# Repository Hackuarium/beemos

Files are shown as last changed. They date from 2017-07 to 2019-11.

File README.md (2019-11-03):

<p align="center">
  
</p>

# BeeMoS - honey Bee Monitoring System<br/> (under development)

_[Lire en français](README.fr.md)_

The BeeMoS project is an open source bee hive monitoring system developed at the open science lab [Hackuarium](http://www.hackuarium.ch), Route de Crochy 20, Ecublens, Switzerland.

Please fee free to [contact us](https://form.jotformeu.com/71600609780354) if you would like more information.

# Objectives

Build and program an open source bee monitoring system capable of the following objectives:

- [x] Track the activity of the hives to study the behaviour of bees and monitor their health.
- [x] Track changes in the hive's weight over time to detect sudden and gradual changes (swarming, honey production ...).
- [x] Measures environmental variables including temperature, humidity, light and atmospheric pressure and study their effect on the bees.
- [ ] Send the data to a remote server for analysis, visualization or to notify the user if something unusual happens.

# Cloning the project

This project uses SUBMODULES

In order to clone use:

`git clone --recurse-submodules https://github.com/hackuarium/beemos`

To update the submodules, enter the folder you created ("beemos") and use:

`git submodule update --recursive --remote`

# Modules

To achieve the above objectives, the project follows a modular design with different hardware components. We use the I2C protocol to make modulles (i.e the boards) communicate to each other while using RJ-12 connectors in order to allow easy plugging/deplugging of different modules.

[**Counter**](counter-i2c/README.md): Counts bees entering and exiting the hive over time using infrared (IR) sensors. Each sensor consists in an IR emitter-receiver, the passage of a bee under the sensor modifies the reflected IR signal. A pair of IR sensors is used for each tunnel so that the direction of bees (i.e. entering or exiting the hive) can be determined.

<p align="center">
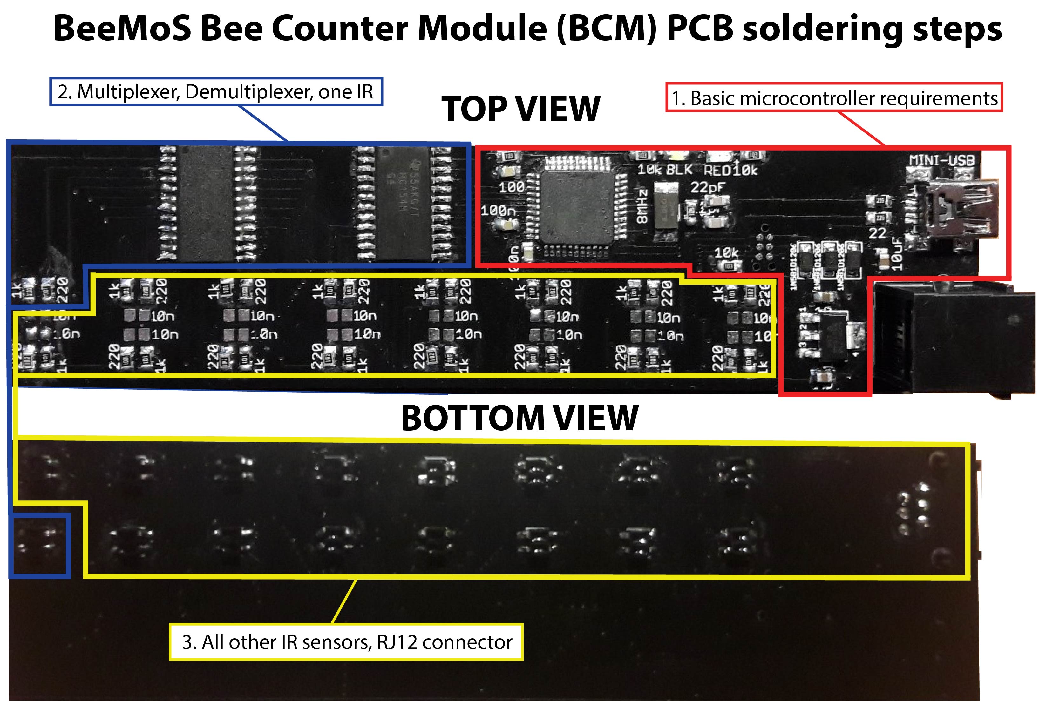
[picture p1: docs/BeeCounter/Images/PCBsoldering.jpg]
  
</p>

Here is the orientation of the IR sensors at the back of the PCB. Be careful, the orientation of the Eagle file is seen from the top of the PCB.
<p align="center">
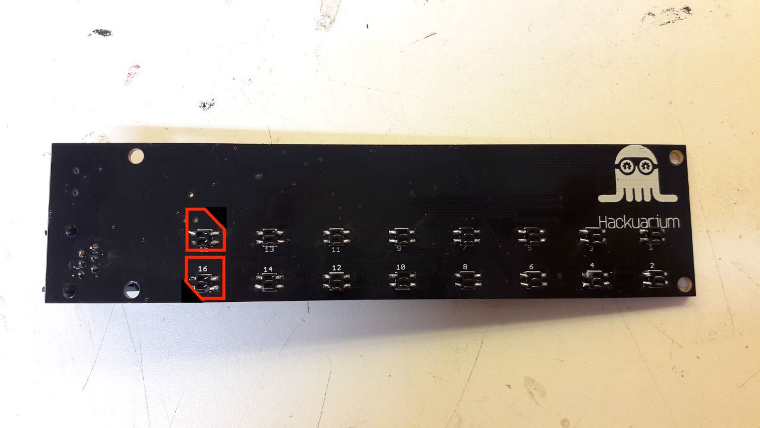
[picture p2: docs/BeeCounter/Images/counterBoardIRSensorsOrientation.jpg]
  
</p>

[**Scale**](scale-i2c/README.md): Weighs the hive periodically using 4 load cells in Wheatstone bridge configuration.

[**Weather station**](weather-i2c/README.md): Monitors temperature, humidity, atmospheric pressure and luminosity outside of the hives.

<p align="center">
  
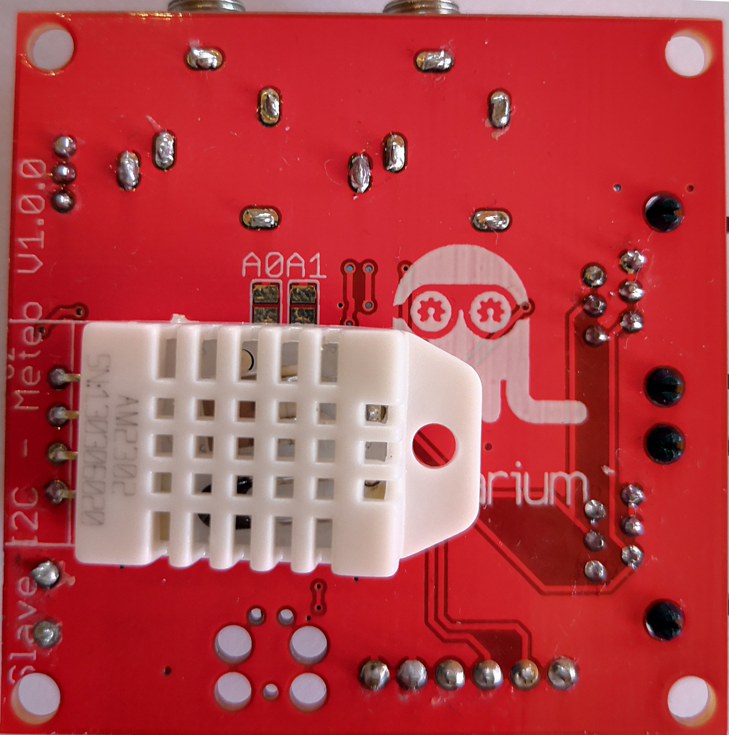
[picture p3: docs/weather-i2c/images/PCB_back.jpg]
  
</p>

[**Master board**](master/README.md): Communicates with all other devices over I2C, log data in memory and sends the data to a remote server. Can also track temperature inside the hive.

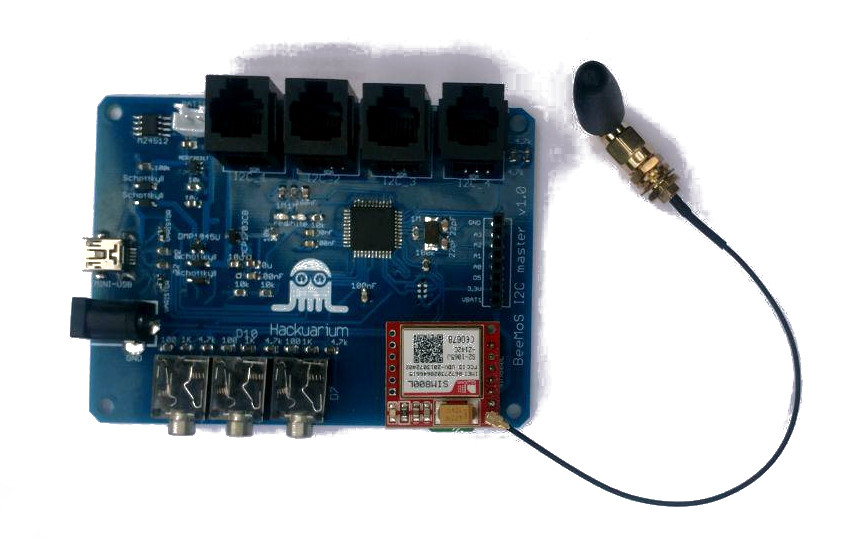
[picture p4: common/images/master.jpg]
  

[**Simple master**](master-simple/README.md): A simple master board with I2C RJ-12 socket to
make some tests.

# State of the project

We have designed and ordered PCBs for the bee counter, weather station, scale and master boards. These four boards have been assembled and programmed. We also built a laser cut wooden enclosure which contains the bee counter PCB. It includes 8 individual gates that the bees use to enter/exit the hive and an upper compartment for the board so that sensor are on top of entering bees. A few field trials were launched to assess the accuracy of the bee counter but we still need to fix some things in the hardware and software to get it working (we detect false positives at the beginning and the end of sunny days, possibly due to sun beams entering and being counted as a passing bee). Similarly we need to further test the scale in order to confirm that measures are stable over long periods of time. 
Clara has joined the BeeMoS team in the summer of 2018 to make some tests of the bee counter in a controlled setting with live bees (transparent box with the beecounter inside and a camera to record video of entering/exiting bees that was compared to the readings from the board) and also participated in building a hive scale. 

<p align="center">
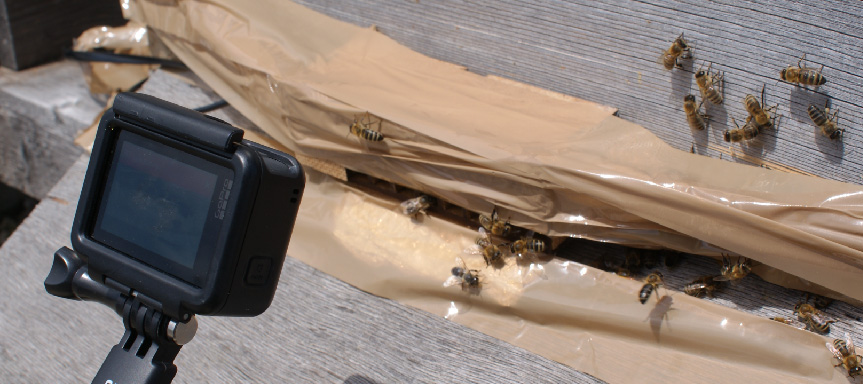
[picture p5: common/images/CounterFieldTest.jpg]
  
</p>

The weather board can now show temperature, humidity, atmospheric pressure and relative light intensity. The scale board v1.0 has been soldered, a minor fix was needed to get it to work. The next steps will be to get the bee counter to work accurately by performing controlled tests, to assess the accuracy of the scale over time and to be able to send data wirelessly, integrate them to a database and plot them in an attractive way. 

We have assembled a complete kit, containing:
- 1 master board
- 1 counter board
- 1 scale board
- 1 weather board (to be protected from rain in a transparent container that lets the light through as well as an entry for the humidity to be accurately measured)
- 1 Si7021 humidity sensor
- 1 solar panel
- 2 temperature sensors (one wire DS18B20)
- 3 cables (RJ11 connectors)
- 1 battery 3.7V, 6600mA/h
- 1 wooden counter box
- 1 plastic box (to protect the master and scale boards from rain)
Here is what the kit actually looks like:
<p align="center">
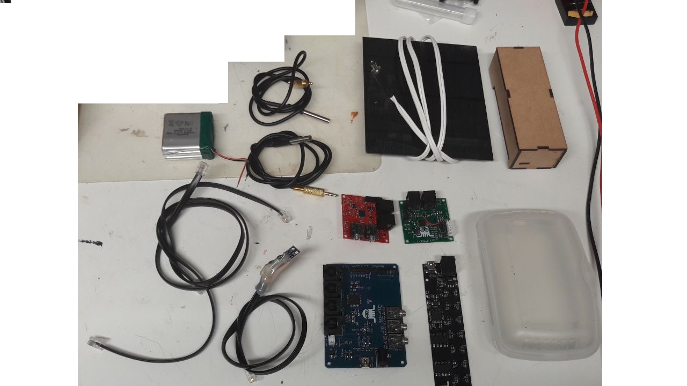
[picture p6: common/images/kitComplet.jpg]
  
</p>

We already have assembled and tested some parts of it (the master, weight and weather boards in particular), but on an empty hive. The master board seems to log correctly and we are able to read the logs afterwards. Some things need to be fixed, for example sometimes the master board stops recording for long periods of time. It seems that this happens when the cables between boards (I2C interface) are too long. Since the 2G network will soon disappear in Switzerland, the SIM800L module will become useless (does not work with 3G and above). We are now (in October 2019) designing a new master board based on the ESP32 in order to be less limited in programming it (less memory limitations than for Atmega32u4-based boards) and also to have integrated WiFi and Bluetooth and possibly LoRa too for wireless communications. Since all the other boards are based on I2C communication, they should be easy to integrate with the new master board. Our current work related to ESP-32 can be found at https://github.com/Hackuarium/esp-32wroom (not tested yet).

# Further resources 

All codes, PCB board and schematic files and documentation can be found on the [BeeMoS github repository](https://github.com/Hackuarium/beemos) (in english only)

View this project on [CADLAB.io](https://cadlab.io/project/1029)

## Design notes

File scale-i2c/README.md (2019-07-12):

<p align="right">
<a href="https://hackuarium.github.io/beemos/">
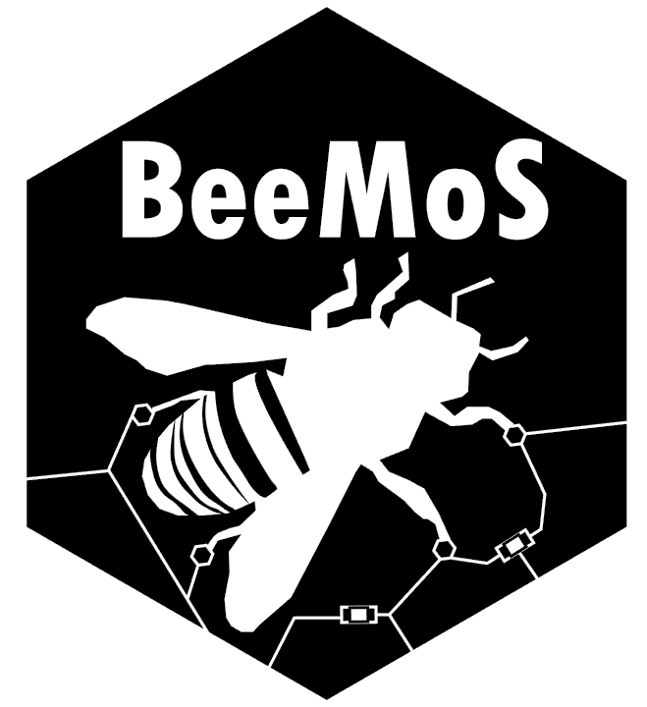
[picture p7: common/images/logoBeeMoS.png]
beemos

</a>
</p>

# Scale

The purpose of this board is to measure the weight of the hive periodically. This allows to detect honey production and swarming. It is an I2C slave that includes a HX711 for weight measurement.

## Hardware components

The following components are present on the board:

Microcontroller: ATmega328

Sensors:

- HX711 Amplifier
- 4X load sensors SEN-10245 (confirm REF)

Connectors:

- 2X RJ12 to connect other boards via I2C

## Programming

After soldering the device you need to add a bootloader.
This device is based on an ATmega328 at 8MHz (3.3v). It is compatible
with an Arduino Fio.

To install the bootloader we are using as cable the tag-connect as well as
a TinyISP module.



Once the bootloader has been flashed you may program using a serial
adaptator like the FT232RL.

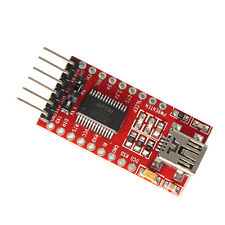
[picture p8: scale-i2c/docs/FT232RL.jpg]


## I2C registers

This device appears like a I2C slave at the address **16** and allows the following commands

| Register address | Description | R/W |
| --- | --- | --- |
| 0: A | Log ID | R |
| 1: B | Seconds since last log | R |
| 2: C | Weight (internal unit) | R |
| 3: D | Weight (g) | R |
| 4: E | Offset (internal unit) | R |
| 5: F | Factor (internal unit) | R |
| 6: G | Minimal weight (internal unit) | R |
| 7: H | Maximal weight (internal unit) | R |
| 8: I | Reference value (in 10g unit)  | R |
| 9: J | Weight (mg) (LOW bits) | R |
| 10: K | Weight (mg) (HIGH bits) | R |
| 13: N | Power supply (in mV) | R |
| 14: O | Logging interval | R/W |
| 15: P | Delay before going to sleep | R/W |

### Actions

Those actions allows to calibrate the scale. Please take care that you need to weight
at least 5s so that the scale stabilize.

| Register address | Description | R/W |
| --- | --- | --- |
| 52: BA | Define empty level | W |
| 53: BB | Define the weight one kg over the tare | W |
| 54: BC | Define low level | W |
| 55: BD | Define high level | W |

### Reference

Before the reference used to be 1kg. A more flexible system had to be
setup in order to deal with small quantities (less than 100g) as well
as large quantities (over 10kg). Therefore the parameter `I` allows to
specifiy the weight of the reference used during calibration.
This value is expressed in decagram (unit of 10g). By default it is
100 (the reference by default is 1kg).

## Performances

- Consumption in sleep mode:
- Consumption awake:

## Making

Wiring the 4 load cells in Wheatstone bridge configuration:

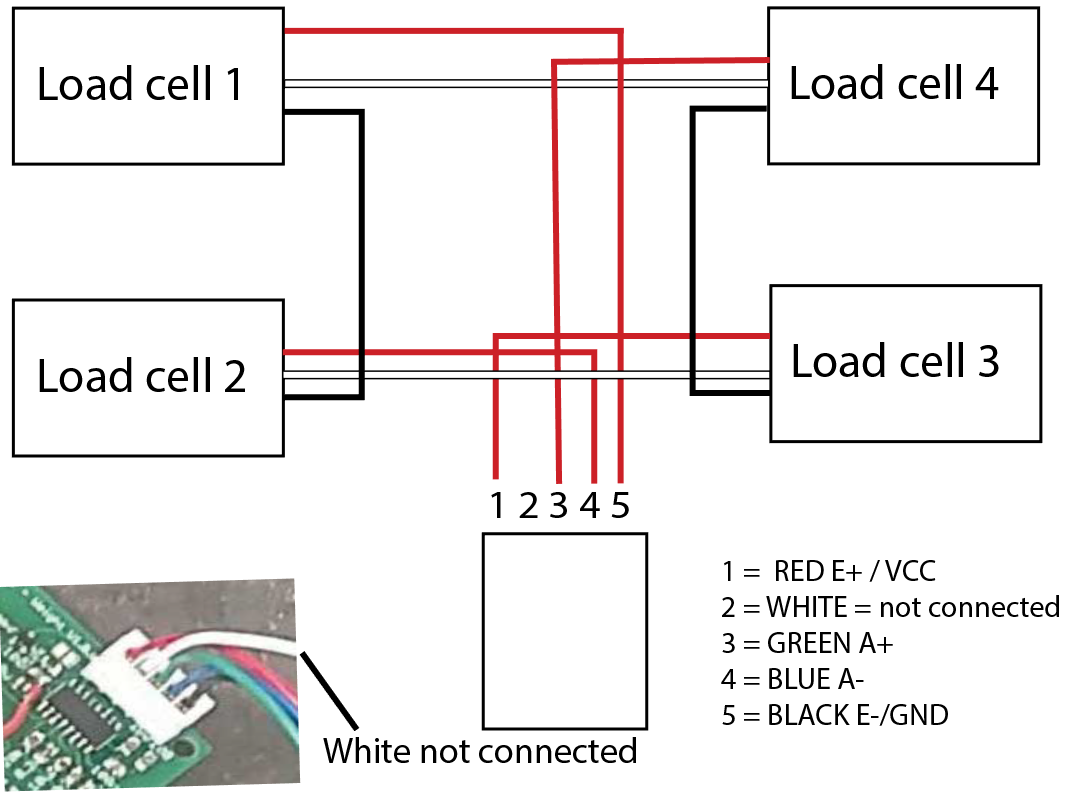
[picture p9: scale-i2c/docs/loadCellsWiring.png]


Version 1.0.0 has 2 small bugs:

- small cable has to be soldered as show in the following picture
- the resistor in the red circle should be 220k instead of 1m (fix out of bound A/D converter scale)

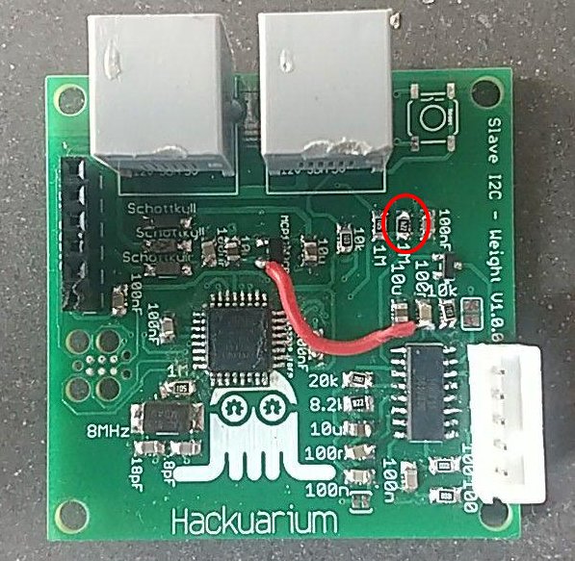
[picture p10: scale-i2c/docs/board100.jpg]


If you want to solder a loading cell you may use the following color cabling

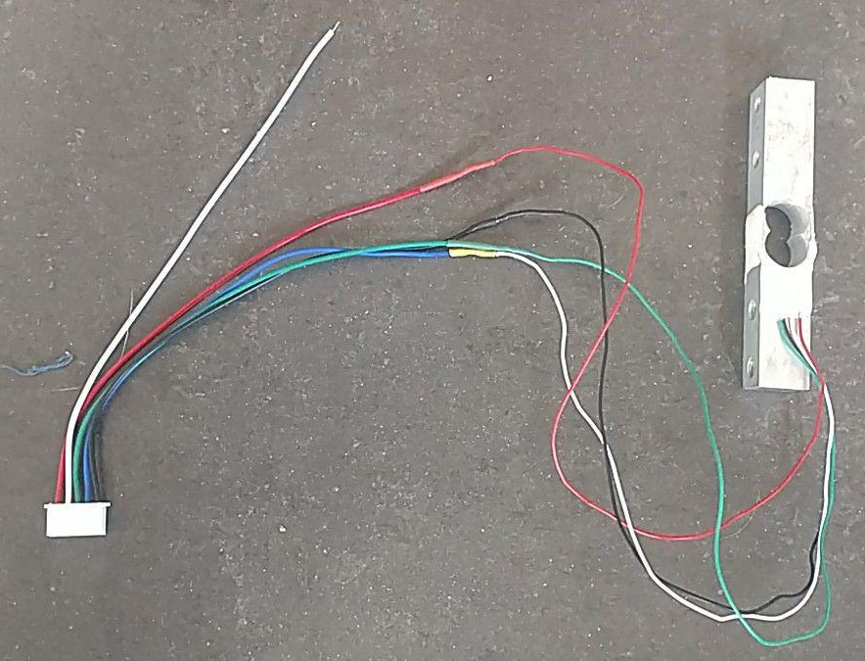
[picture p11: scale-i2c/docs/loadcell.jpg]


Final global view:

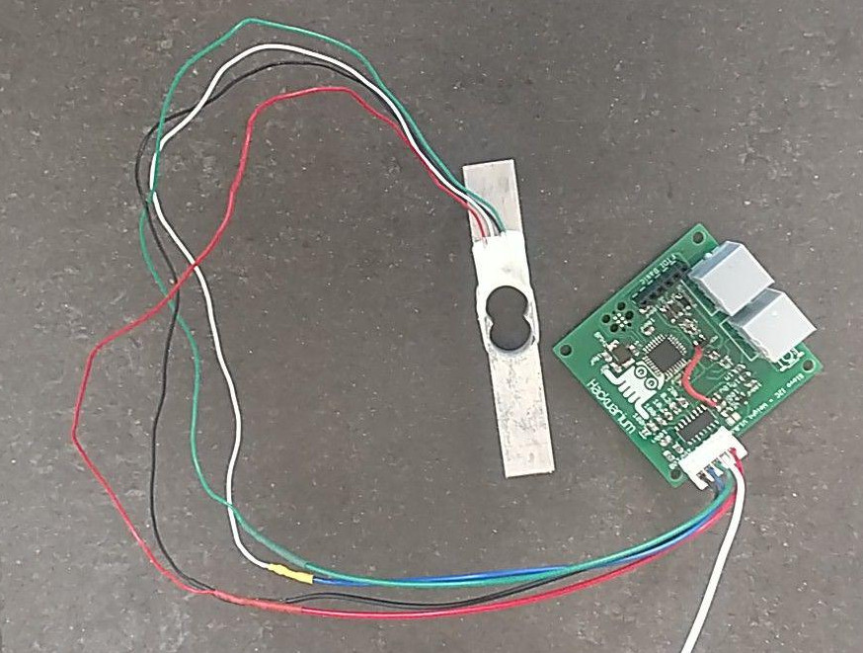
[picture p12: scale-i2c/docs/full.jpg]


## Creation of the stand

To create a base for the load cells, we assembled two wood boards together and glued the load cells between them. We carved a hole under each load cell to allow them to be pressed. On the first scale metallic hinges were added to fix the two boards together. On the second and third scales, wooden pins were fixed on the underboard and complementary holes were created in the upperboard. In both cases, the scale can still be dismantled and movement is permitted in the vertical direction. Newborn bees chew on the wax cap to emerge from the brood frame which produces wax debris that fall. In order to avoid accumulation of these debris on the wood board, a rectangular hole was made in the center of the two boards.
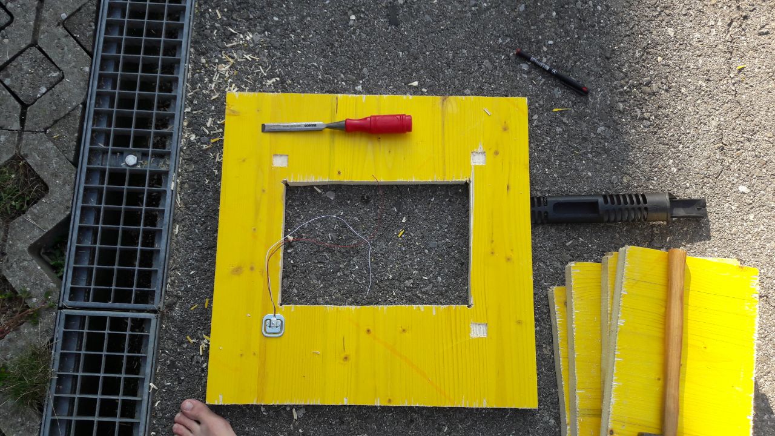
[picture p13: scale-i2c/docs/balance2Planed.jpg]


Here is the inside of the first scale built:
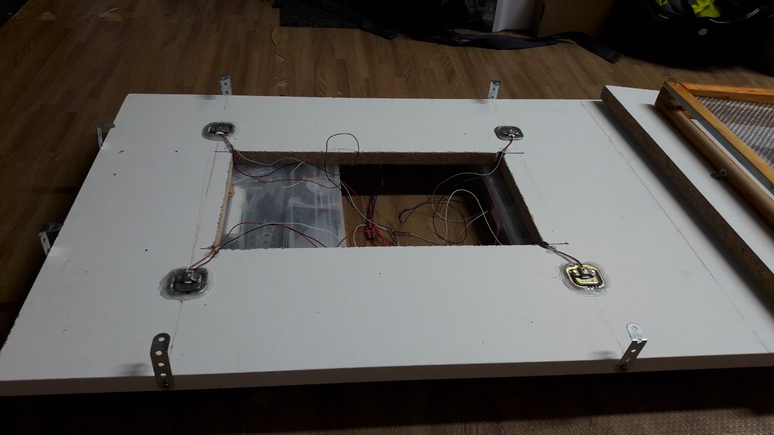
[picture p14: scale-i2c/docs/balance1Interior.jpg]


The inside of the second scale:
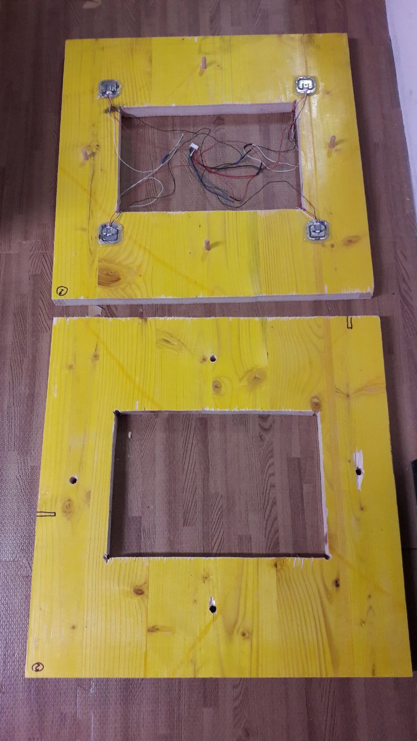
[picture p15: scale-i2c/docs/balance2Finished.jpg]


What it looks like assembled:
The wooden piece with the fence is the base of the hive.
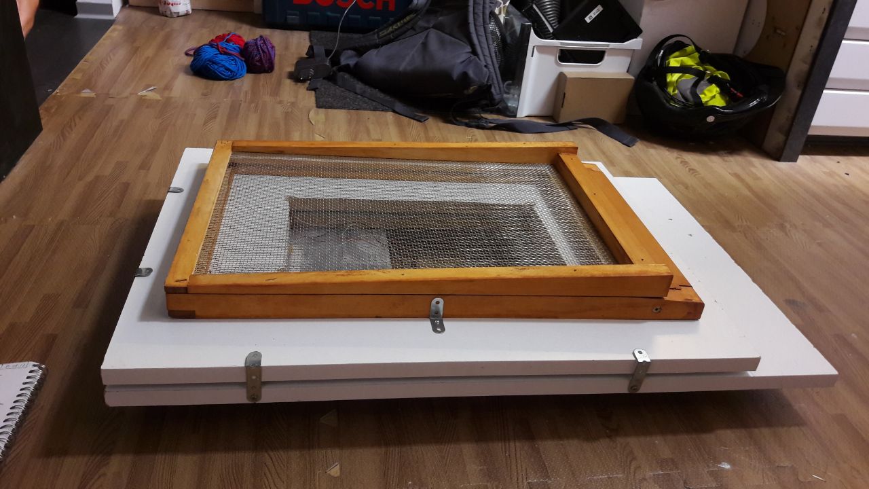
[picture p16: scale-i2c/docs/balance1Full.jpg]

.
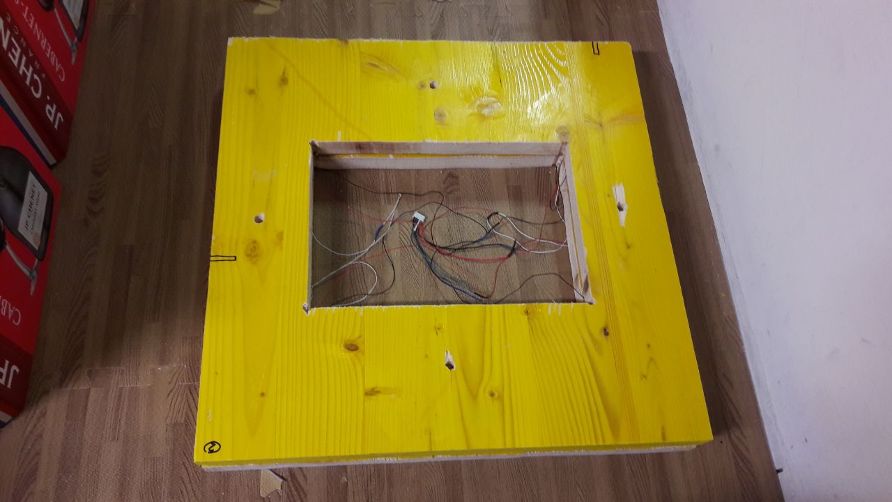
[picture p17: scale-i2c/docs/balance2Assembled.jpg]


We then tested if the weight was correctly measured by calibrating the scale with 1L of milk, and then adding more and more cartons of milk. The results were encouraging, but we tested only up to 15kg. Next steps will be to test with a complete hive and to test the stability of the measurement as time goes by.
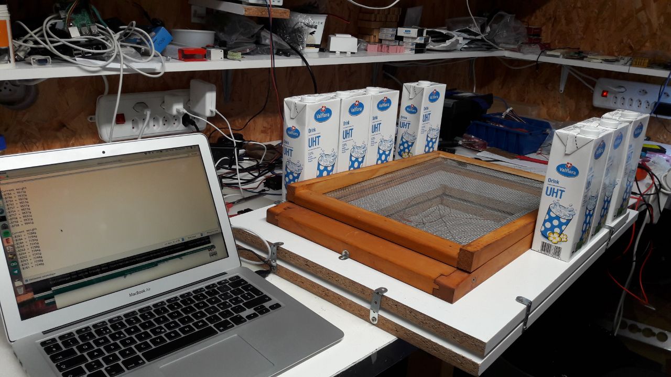
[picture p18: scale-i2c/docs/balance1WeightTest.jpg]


To date, we built three full scales that seems to be working.

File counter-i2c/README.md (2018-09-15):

Bee-counter i2c

<p align="right">
<a href="https://hackuarium.github.io/beemos/">
beemos
</a>
</p>

# Bee-counter i2c

Using an Arduino based microcontroller, infrared (= IR) reflectance sensors are used to detect if a bee is present under the sensor, thereby modifying the reflected IR signal read by the microcontroller. Each gate consists of two IR reflectance sensors, each capable of emitting and receiving an IR signal. This allows to determine whether the bee is entering or exiting the hive by looking at which of the two sensors reacted first to the presence of the bee below it.

## Components

- x1 Microprocessor Atmel 32u4 (similar to Arduino Leonardo boards), 8Mhz, 3.3V
- x16 QRE1113 IR reflectance sensors (x2 per gate)
- x1 74HC154W demultiplexer used to switch on the IR led of one of the 16 IR reflectance sensors
- x1 74HC4067 multiplexer used to read the value from one of the IR reflectance sensors (the one which has the IR led on)

## Performances

Scanning all 16 IR sensors: 3ms
Current consumption: 27mA

## The box

The box consists in a laser cut wooden enclosure, which contains the bee counter PCB. It includes 8 individual gates that the bees use to enter/exit the hive and an upper compartment for the board so that sensor are on top of entering bees.

## Parameters

There are 26 parameters:

| ID  | Name | Description |
| --- | --- | --- |
| 0 | PARAM_LOGID | the log ID |
| 1 | PARAM_SECONDS | the number of seconds since the last log |
| 2 | PARAM_GATE1_IN | gate 1 counter of events IN |
| 3 | PARAM_GATE1_OUT | gate 1 counter of events OUT |
| 4 | PARAM_GATE2_IN | gate 2 counter of events IN |
| 5 | PARAM_GATE2_OUT | gate 2 counter of events OUT |
| 6 | PARAM_GATE3_IN | gate 3 counter of events IN |
| 7 | PARAM_GATE3_OUT | gate 3 counter of events OUT |
| 8 | PARAM_GATE4_IN | gate 4 counter of events IN |
| 9 | PARAM_GATE4_OUT | gate 4 counter of events OUT |
| 10  | PARAM_GATE5_IN | gate 5 counter of events IN |
| 11  | PARAM_GATE5_OUT | gate 5 counter of events OUT |
| 12  | PARAM_GATE6_IN | gate 6 counter of events IN |
| 13  | PARAM_GATE6_OUT | gate 6 counter of events OUT |
| 14  | PARAM_GATE7_IN | gate 7 counter of events IN |
| 15  | PARAM_GATE7_OUT | gate 7 counter of events OUT |
| 16  | PARAM_GATE8_IN | gate 8 counter of events IN |
| 17  | PARAM_GATE8_OUT | gate 8 counter of events OUT |
| 20  | PARAM_THRESHOLD | the threshold of absorbance to reach to conclude there is a bee crossing the gate |
| 21  | PARAM_THRESHOLD_RESET  | the threshold of absorbance to conclude that the event is finished |
| 22  | PARAM_DEBUG_REPEAT | the duration of the gate debug monitoring |
| 23  | PARAM_DEBUG_DELAY | the delay between two successive displays of debug information |
| 24  | PARAM_LOGGING_INTERVAL | the time interval between two logs (should be at least 300s) |
| 25  | PARAM_DEBUG_PRINT | a boolean to enable the debug mode. `Z1` allows to enable debug, `Z0` to disable it. |

## Menu and commands

Here is the actual menu, accessible by typing "h" + enter.

- (h)elp
- (s)ettings
- (u)tilities
- (b)ackground
- (c)ounter
- (g)ate debug bg
- (l)og

`Settings` gives access to the current values of the settings. To change the value of a setting, just type the letter of the setting (A-Z) and the new value of the setting in the chat box and press enter.
`Gate debug mode` activates the real-time monitoring system. Each time a bee pass through a tunnel, the time, the number of the gate, the absorbance values of the two sensors and the number of bees outside is displayed.

## When do we have an event ?

The system will calculate the background which is the value of the receiver when no bee is in the gate.
In order to evaluate this background, the last 15 values of each detector and the background will
be the median of those values.

An event will start when the change observe to a detector is larger than `PARAM_THRESHOLD`. This event
will finish when this value will go under ``PARAM_THRESHOLD_RESET`.

In order to well detect an event it would make sense that the value of ** the background is between
96 and 160 **. A low value means that the receiver receives too much IR. We could ensure that the voltage
is really 3.3v and if it is the case we could think about a high resistor value for the IR led.

You can easily check the background values using the option `b`.

## Gate validation (tested with USB and MCP1703-50)

In order to validate the board it is practical to use a Q-tip and to use the `gate debug bg`
menu item (`g`).

This mode will check for absolute value variation compared to the background value.
If this variation is over the `PARAM_THRESHOLD` the value will be displayed. The measurements are done
and display the value`PARAM_DEBUG_REPEAT` times and separated by `PARAM_DEBUG_DELAY` (500, which means 500 ms,
is a good value).

With a Q-tip we should detect a variation for the "in" and "out" detector of each gate.

In the following logs we can see that the Gate 1 and 3 have problems because both event are not detected.

```
Gate 1 - Inside: 2  - Outside: 39
Gate 1 - Inside: 3  - Outside: 38
Gate 1 - Inside: 3  - Outside: 33
Gate 1 - Inside: 0  - Outside: 13
Gate 1 - Inside: 1  - Outside: 24
Gate 1 - Inside: 3  - Outside: 36
Gate 1 - Inside: 3  - Outside: 38
Gate 1 - Inside: 0  - Outside: 17
Gate 2 - Inside: 1  - Outside: 5
Gate 2 - Inside: 11 - Outside: 12
Gate 2 - Inside: 13 - Outside: 11
Gate 2 - Inside: 14 - Outside: 11
Gate 2 - Inside: 14 - Outside: 11
Gate 2 - Inside: 12 - Outside: 12
Gate 3 - Inside: 11 - Outside: 2
Gate 3 - Inside: 10 - Outside: 2
Gate 3 - Inside: 10 - Outside: 1
Gate 3 - Inside: 10 - Outside: 2
Gate 4 - Inside: 7  - Outside: 12
Gate 4 - Inside: 6  - Outside: 10
Gate 4 - Inside: 6  - Outside: 11
Gate 4 - Inside: 8  - Outside: 11
Gate 4 - Inside: 2  - Outside: 7
```

If we look at the background values (`b`) we obtain:

```
0 19 19 19 19 19 19 19 19 19 19 19 19 19 19 19 25
1 3B 3B 3C 3C 3C 3C 3C 3C 3C 3C 3C 3C 3C 3C 3C 60
2 23 23 23 23 23 23 23 23 23 23 23 23 23 23 23 35
3 20 1F 20 20 20 20 20 20 20 20 20 20 20 20 20 32
4 22 22 22 22 22 22 21 22 22 22 22 22 22 22 21 34
5 18 18 17 17 18 17 18 17 17 17 18 17 18 17 17 23
6 1D 1D 1D 1D 1D 1D 1D 1D 1D 1D 1D 1D 1D 1D 1D 29
7 20 20 20 20 20 20 20 20 20 20 20 20 20 20 20 32
8 3B 3B 3B 3B 3B 3B 3B 3B 3B 3B 3B 3B 3B 3B 3B 59
9 1A 1A 1A 1A 1A 1A 1A 1A 1A 1A 1A 1A 1A 1A 1A 26
10 29 29 29 29 29 29 29 29 29 29 29 29 29 29 29 41
11 20 20 21 21 21 21 21 21 21 21 21 21 21 21 21 33
12 23 23 23 23 23 23 23 23 23 23 23 23 23 23 23 35
13 27 27 27 27 27 27 27 27 27 27 27 27 28 27 27 39
14 2D 2C 2C 2D 2C 2D 2D 2D 2D 2D 2D 2D 2C 2D 2C 45
15 1B 1B 1B 1B 1B 1C 1B 1B 1C 1B 1B 1B 1B 1B 1B 27
```

The variation between the values are huge and the origin is currently unknown.

## Studying the background (MCP1703-50)

Conditions:

- power supply is USB
- convert is MCP1703-50 !!! (5v) so the voltage should be close to 4.7 !

We did various tests to get the average value depending the surface and the distance. In order
to make the measurement we use a very simple setup in which we control the distance between the
PCB and the surface.

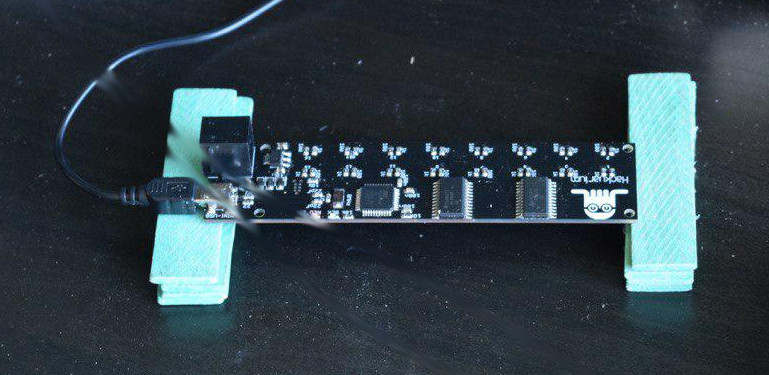
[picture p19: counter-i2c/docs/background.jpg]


| Surface | Distance [mm] | Value | SD |
| --- | --- | ----- | ----- |
| Black wood  | 2 | 157 | 16.51 |
| Black wood  | 4.5 | 234 | 2.94  |
| Black wood  | 5.3 | 239 | 3.32  |
| Black wood  | 6 | 245 | 3.32  |
| Black wood  | 8.5 | 249 | 3.86  |
| Black wood  | 10 | 250 | 4.96  |
| Black wood  | 12 | 251 | 5.59  |
| MDF | 2 | 18 | 0.50  |
| MDF | 4.5 | 20 | 0.62  |
| MDF | 5.3 | 21 | 0.48  |
| MDF | 6 | 26 | 7.84  |
| MDF | 8.5 | 104 | 14.38 |
| MDF | 10 | 144 | 9.58  |
| MDF | 12 | 169 | 12.44 |
| White paper | 2 | 18 | 0.45  |
| White paper | 4.5 | 20 | 0.50  |
| White paper | 5.3 | 22 | 0.45  |
| White paper | 6 | 26 | 4.27  |
| White paper | 8.5 | 119 | 19.22 |
| White paper | 10 | 141 | 10.87 |
| White paper | 12 | 182 | 11.61 |

We observe that it is barely possible to measure anything on black surface. MDF or white
paper is ok but the distance is critical.

The analysis of the background log (obtained with `b`) can be processed [online on this webpage](https://www.cheminfo.org/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).

What we observe is that when we have around 5mm the SD is huge. Nevertheless as shown with the values the stability is really good.

We find here the 16 detectors with for each of them 15 values in hexadecimal that corresponds
to the A/D conversion of the received signal. The acquisition is done every second during
15 seconds. The last value (in decimal), used for the statistics,
is the median of the 15 other values.

```
0 30 30 30 30 30 30 30 30 30 30 30 30 30 30 30 48
1 35 35 35 35 35 35 35 35 35 35 35 35 35 35 35 53
2 76 76 76 76 76 76 76 76 76 76 76 76 76 76 76 118
3 4F 50 4F 4F 50 4F 50 4F 4F 4F 4F 50 4F 4F 50 79
4 7B 7A 7A 7A 7A 7A 7A 7A 7A 7A 7A 7A 7A 7B 7A 122
5 45 45 46 45 45 45 45 45 45 45 45 45 45 45 45 69
6 76 76 76 76 76 76 76 76 76 76 76 76 76 76 76 118
7 54 54 54 54 54 54 54 54 54 54 54 54 54 54 54 84
8 84 84 83 83 84 83 84 83 83 83 84 83 84 84 83 131
9 4E 4F 4F 4F 4F 4E 4F 4E 4F 4F 4F 4E 4F 4F 4E 79
10 76 76 76 76 76 76 76 76 75 76 76 76 76 76 76 118
11 52 52 52 52 52 52 52 52 52 52 52 52 52 52 52 82
12 74 74 74 74 74 74 74 74 74 75 74 74 74 75 74 116
13 57 58 57 58 57 57 58 57 57 57 58 57 57 57 57 87
14 6F 6F 6F 6F 6F 6F 6F 6F 6F 6F 6F 6F 6F 6F 6F 111
15 4E 4E 4E 4E 4E 4E 4E 4E 4E 4E 4E 4E 4E 4E 4E 78
```

## Studying the background (MCP1703-33)

Conditions:

- power supply is USB
- convert is MCP1703-33

| Surface | Distance [mm] | Value | SD |
| --- | --- | ----- | ----- |
| Black wood  | 3 | 212 | 8.43  |
| Black wood  | 6 | 243 | 10.37 |
| Black wood  | 8.5 | 251 | 15.68 |
| Black wood  | 9 | 252 | 18.66 |
| Black wood  | 13 | 253 | 13.19 |
| Black wood  | 16 | 254 | 33.96 |
| MDF | 2 | 23 | 0.45  |
| MDF | 4.5 | 26 | 1.24  |
| MDF | 5.3 | 44 | 17.91 |
| MDF | 6 | 77 | 26.16 |
| MDF | 8.5 | 163 | 15.92 |
| MDF | 10 | 186 | 15.04 |
| MDF | 12 | 207 | 17.59 |
| White paper | 2 | 24 | 43.37 |
| White paper | 4.5 | 25 | 1.09  |
| White paper | 5.3 | 31 | 18.74 |
| White paper | 6 | 42 | 26.62 |
| White paper | 8.5 | 161 | 24.23 |
| White paper | 10 | 173 | 23.97 |
| White paper | 12 | 188 | 13.31 |

The results are very heterogenous for this board, as it is possible to see with the standard errors.

## Experiments

In order to assume the precision of the bee counter, we set an experiment as follows:
We built inside a transparent tupperware two hermetic compartments, one with sugared water, the other one with pollen. The bees can only pass from one compartment to another through the box containing the tunnels with the IR reflectance sensors. With a camera, we filmed the tupperware to then compare the results of the gate monitoring debug system with the footage of the camera.

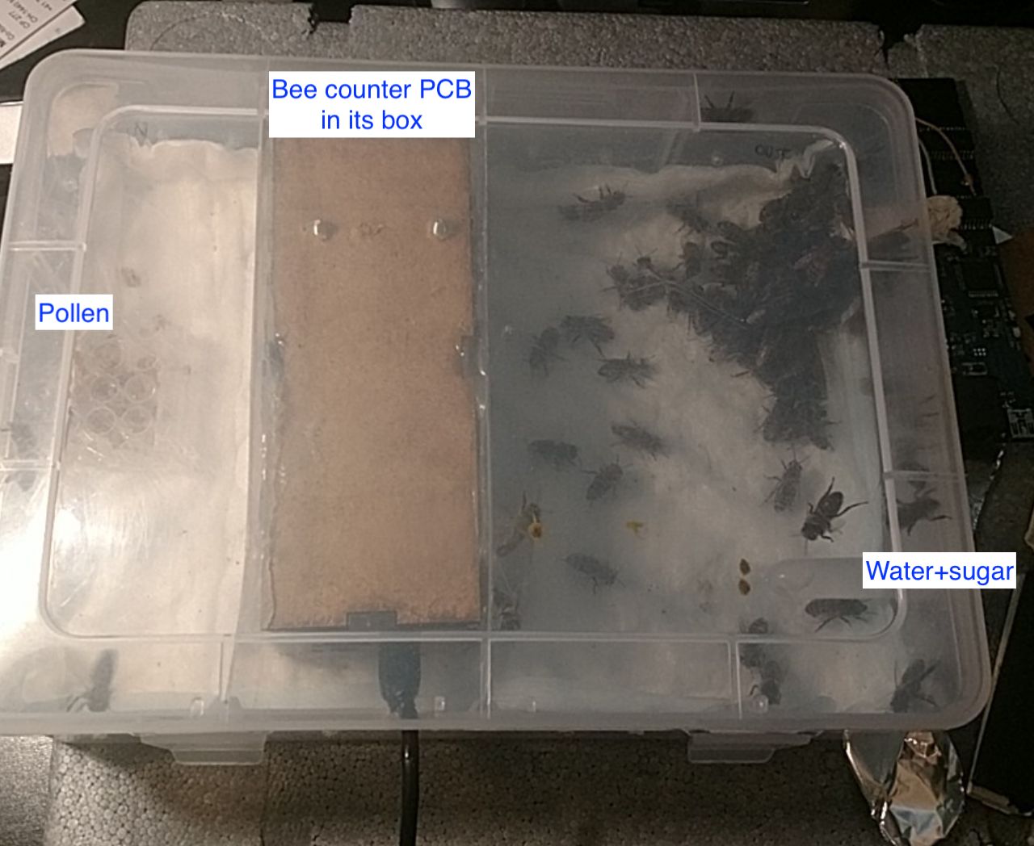
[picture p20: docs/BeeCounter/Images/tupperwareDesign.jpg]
Tupperware Design


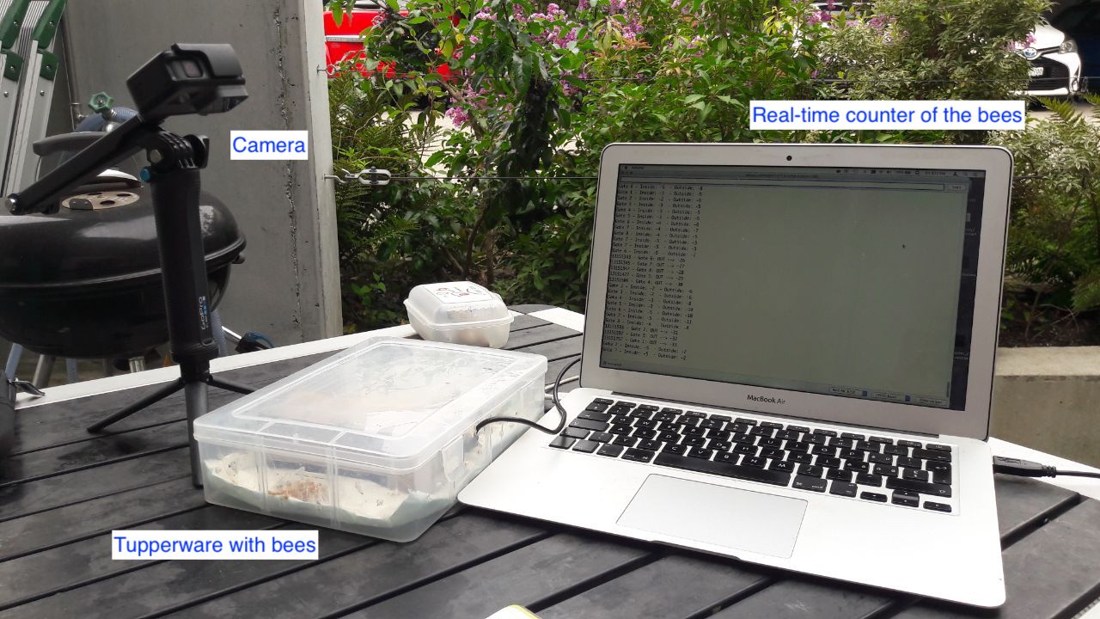
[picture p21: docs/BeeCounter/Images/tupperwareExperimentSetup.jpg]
Tupperware Experiment Setup


## Results

The monitoring system seems to be functional. Every bee passing through is counted and in the right sense (IN or OUT).
There is still some problems yet to be fixed:

- The bees have the tendency to poke their head through the tunnel without crossing it, thus triggering the sensors even when they don't cross the box. One possible solution to be tested is to extend a little the length of the tunnel.
- As the sensors are placed on one side of the box, they are easily triggered by quick changes in brightness (for example a hand moving over the tupperware). This problem should be solved when the box will be placed inside a hive, because the side with the sensors will be facing the inside of the hive, thus preventing such rapid changes.

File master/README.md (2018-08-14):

## Master board

This board allows to connect SIM800L as well as I2C slaves.

It also has a flash memory of 64Kb.

### SIM800L

## Experiments

[August 14, 2018](docs/20180814/README.md)

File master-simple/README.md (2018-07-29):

<p align="right">
<a href="https://hackuarium.github.io/beemos/">
beemos
</a>
</p>

# Master board
This board is connected to all other modules via i2c and sends all the data to a remote server using a SIM card. It also uses a temperature sensor to monitor the internal temperature of the hive. 

_We are currently using a simplified version of the Master board for debugging purpose. A more complete version with the temperature sensor will come later and is in development._

## Components
* x1 Microprocessor Atmel 32u4 (similar to Arduino Leonardo boards), 8Mhz, 3.3V
* x3 RJ12 connectors

## Performances

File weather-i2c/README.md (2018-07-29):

<p align="right">
<a href="https://hackuarium.github.io/beemos/">
beemos
</a>
</p>

# Meteo station I2C

The goal of this project is to create a small board that contains many sensors and that can be used as a meteo station. This board is controlled by the master board and acts as an I2C slave. The board is in sleep mode by default and is only waked up by the master board when it requires data.

## Hardware components

The following components are present on the board:

Microcontroller: ATmega328

Sensors:
* DHT-22 humidity sensor
* DS18B20 for temperature
* Photoresistor for light

Connectors:
* 2X RJ12 to connect other boards via I2C
* 2X 3.5mm jack to eventually connect additional sensors.

## I2C commands

This device appears like a I2C slave at the address XXX and allows the following commands

## Performances
* Consumption in sleep mode: 20µA
* Consumtpion awake: 3.8mA

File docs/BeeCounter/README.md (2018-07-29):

# BeeMos bee counter module (BCM) documentation

## BCM PCB soldering and debug instructions <br/>(_UNDER CONSTRUCTION_)



### 1. Soldering (part 1)

Solder the basic elements to make the microcontroller work as shown in the picture above in red (starting with the hardest/riskiest to solder):
* Microcontroller
* Mini USB port
* Voltage regulator
* 2x 22 Ohm resistors
* 3x 10 uF capacitors
* 3x Shottky diodes (direction matters)
* 4x 10k Ohm resistors
* 3x 100 nF capacitors
* 1M F capacitor
* 2x 22 pF capacitors
* 8 Mhz cristal
* Blank/white LED (direction matters)
* Red LED (direction matters)

### 2. Power

Power the board by connecting the USB cable (one LED should turn on), check immediately that the USB port or the microcontroller are not overheating by touching them with your fingers (a few seconds are usually enough to know)

### 3. Initial test

#### Bootloader

Choose "Lilipad USB" as board in the Arduino IDE, then burn bootloader with USBtiny in-circuit programmer and JTAG cable in contact with the ISP pins of the board until the bootloader has finished to burn

#### Uploading test

Connect the board to computer with USB cable, upload a simple "blink" sketch, confirm that the sketch was indeed uploaded (i.e. confirm that the LED is indeed blinking)

### 4. Soldering (part 2)

**IMPORTANT:** in PCB version 1.0, the two resistors are labelled "220" and "1k", DO NOT USE THESE VALUES.Use 100 Ohm instead of 1 kOhm and 1 kOhm instead of 220 Ohm and do not solder the 10 nF capacitor.  

Disconnect the USB cable and solder the demultiplexer, the multiplexer and 1 IR emitter/receptor (QRE1113) as shown in blue in the above picture. Try not to spend to much time while soldering to avoid overheating of the component. Solder the two associated resistors (see note below before doing so).

### 5. IR LED emission test

#### Upload sketch

Reconnect the USB cable, choose the Lilipad USB as board (`Tools` > `Board` > `Lilipad USB`), select the port where it is connected (this should appear under `Tools` > `Ports` as ttyACM0 (Lilipad USB) ) and upload the Arduino sketch in `counter-i2c/arduino`.

#### LED check

* Option A: Check that the IR LED is emitting either using an oscilloscope between  ~~pins X and Y~~

* Option B: Use the camera of your phone (you should see a purple beam, although this works more or less depending on your phone/camera, you can try to go in a dark place and change the angle between the camera and the board to better see the IR beam, see picture below).

In case you see no signal from the IR LED, make sure soldering is appropriate and if fiddling with soldering doesn't work, try replacing the QRE1113 sensor (some have failed  during our test perhaps due to overheating during soldering or manufacture issues)

### 6. Final soldering and IR checks

Disconnect USB cable and solder the 15 other QRE1113s, their associated resistors and the RJ12 connector as indicated in yellow in the above image.

Repeat the IR LED emission test (from step 5) on all other QRE1113s until all work

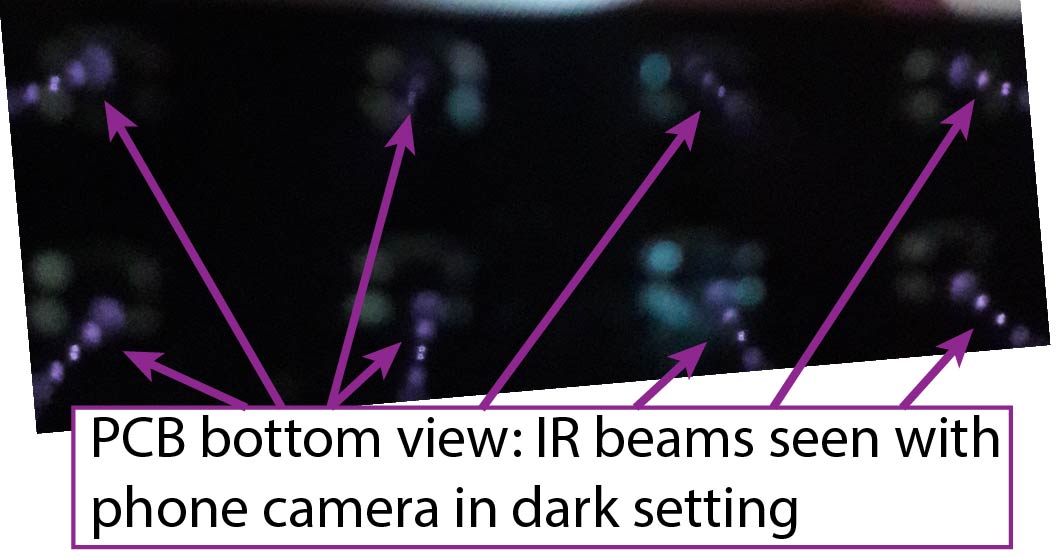
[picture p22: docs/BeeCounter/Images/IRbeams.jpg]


### 7. Final test

#### Opening the serial monitor

To test the board, connect the USB cable, open the serial monitor in Arduino IDE and make sure to choose the "Both NL & CR" option at the bottom right of the serial monitor (needed to have access to the menu).

#### Interacting with the board

You can use the serial monitor to send different instructions to the BCM. Below is a list of the instructions avaiable.

* h + ENTER: Help menu that will show you the different menus you can enter by typing the first letter + ENTER.
* c + ENTER: Show the hexadecimal values of the IR values read from the sensors. When passing your finger or a pencil over a sensor, you should see its corresponding value change.
* s + ENTER: Display the current values of settings A to Z.
    * A: Log ID
    * B: Number of seconds since the card was started (uptime)
    * C: number of exiting bees through gate 1
    * D: Number of entering bees through gate 1
    * E: Number of exiting bee through gate 2
    * F: Number of entering bees through gate 2
    * etc...

You can move a pencil over a gate in both direction and retype 's'+ENTER to update the values on the serial monitor screen.

### 10. Install the PCB in its laser cut box

### 11. Test in the field

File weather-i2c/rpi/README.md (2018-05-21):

You need to activate the i2c interface

```
sudo raspi-config
```
And check the fifth option.

You should also install the `i2c-tools`:

```
sudo apt-get install -y i2c-tools
```

You may now check the device connected on the i2c port:

i2c-tools 1

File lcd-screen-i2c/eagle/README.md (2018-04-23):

# LCD 16x2 slave
# ATmega328 pin map

| Pin | Map to | Function | Remarks
| --- | --- | --- | ---
| D0 | PD0(RXD) | RX |
| D1 | PD1(TXD) | TX |
| D2 | PD2(INT0) | Rot A | Interrupt allows wake up
| D3 | PD3(INT1) | Rot Int  | Interrupt allows wake up
| D4 | PD4(XCK/T0) | Rot B |
| D5 | PD5(T1) | LCD E | Counter
| D6 | PD6(AIN0) | LCD DB4  |
| D7 | PD7(AIN1) | LCD DB5  |
| D8 | PB0(ICP) | LCD DB6  |
| D9 | PB1(OC1A) | LCD DB7  | PWM
| D10 | PB2(SS/OC1B)  | LCD A | PWM
| D11 | PB3(MOSI/OC2) | MOSI |
| D12 | PB4(MISO) | MISO |
| D13 | PB5(SCK) | SCK |
| D14 A0 | PC0(ADC0) | LCD VDD  | ADC
| D15 A1 | PC1(ADC1) | | ADC
| D16 A2 | PC2/ADC2) | | ADC
| D17 A3 | PC3(ADC3) | | ADC
| D18 A4 | PC4(ADC4/SDA) | SDA |
| D19 A5 | PC5(ADC5/SCL) | SCL |
w

Remarks
* RX, TX used for serial communication over USB (debug)
* SDA, SCL: I2C communication with master
* MOSI, MISO, SCK: boot loader

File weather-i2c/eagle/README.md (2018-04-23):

# ATmega328 pin map

| Pin | Map to | Function | Remarks
| --- | --- | --- | ---
| D0 | PD0(RXD) | RX |
| D1 | PD1(TXD) | TX |
| D2 | PD2(INT0) | | Interrupt allows wake up
| D3 | PD3(INT1) | | Interrupt allows wake up
| D4 | PD4(XCK/T0) | |
| D5 | PD5(T1) | LDR PWR  | Counter
| D6 | PD6(AIN0) | DHT22 |
| D7 | PD7(AIN1) | DHT22 PWR|
| D8 | PB0(ICP) | SCL MAST |
| D9 | PB1(OC1A) | SDA MAST | PWM
| D10 | PB2(SS/OC1B)  | TEMP PWR | PWM
| D11 | PB3(MOSI/OC2) | MOSI |
| D12 | PB4(MISO) | MISO |
| D13 | PB5(SCK) | SCK |
| D14 A0 | PC0(ADC0) | LDR | ADC
| D15 A1 | PC1(ADC1) | TEMP 1 | ADC
| D16 A2 | PC2/ADC2) | TEMP 2 | ADC
| D17 A3 | PC3(ADC3) | TEMP 3 | ADC
| D18 A4 | PC4(ADC4/SDA) | SDA SLAV |
| D19 A5 | PC5(ADC5/SCL) | SCL SLAV |
| D20 A6 | ADC6 | I2C A0 | ADC only input
| D21 A7 | ADC7 | I2C A1 | ADC only input

Remarks
* RX, TX used for serial communication over USB (debug)
* SDA, SCL: I2C communication with master
* MOSI, MISO, SCK: boot loader

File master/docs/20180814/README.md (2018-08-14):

## 2018.08.14

In this first experiment we left the master outside during 10 days hoping to get log information. The master is connected to:

- a weather station (with 2 external probes)
- a scale
- 3 external temperature probe
- a rechargeable battery of 1200 mAh
- a solar panel

## Check the logs

If you connect by Serial to the master you can retrieve all the log using the
command `lm`.

This file can be analysed [on this webpage](https://www.cheminfo.org/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).

The results of this experiment can be found [here](20180814.txt).

## Problems

### Logging interval

One log was expected to be taken every 15 minutes. However it appears that you can not make a nilThreadSleepMS of 15 _ 60 _ 1000. We changed the program so that we sleep 15 \* 60 times 1000ms.

### Errors

We have in the logs some errors (zero values).

It seems that those errors are systematically due to I2C communication problems. In
the current implementation if no byte is received from the I2C slave a 0 value is
set. It was changed to have the ERROR_VALUE (-32768)

### Battery

During the experiment and even with some sunny day the battery is nearly empty.
The consumption is currently to high but in this first experiment the slaves
(scale and weather) never go to sleep.

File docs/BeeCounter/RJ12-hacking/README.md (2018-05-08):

## Title

### Using the RJ12 for light / temperature / power

[RJ12 Hacking](rj12-hacking.md)

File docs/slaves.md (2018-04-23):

# Smart Slaves

A smart slave is an I2C slave that can be connected to a master board.
The slave will be usually be powered by the master board as well and may
receive 12V as well as anything between 3.6 and 6V. The idea is that
the slave will not get a regulated current and it could come from a 
solar panel, a battery or a regulated power source.

Each slave will have a specific base I2C address that can be tuned
using the A0 and A1 jumper. By default it is the base address and you
may add repectively 1 or 2 by soldering A0 and A1.

The I2C bus should be free of any other devices. If some companents
are using the I2C bus a software I2C library should be installed.

## Power consumption

The slave should be able to reach in sleep mode less than 25 µA. This
means that all the devices should be powered from the CPU in order to
completely cut off the current.

## Debugging

A slave must have currently a crystal in order to work with external
clock at 8MHz. This is not the default behaviour of the ATMEGA328 that
works on the internal clock. However it seems that the internal clock 
is not precise enough (up to 5% error ?) and therefore USART communication
may be very difficult.

USART communication (RX and TX) is mainly used for development and this part
could be removed later.

This is also the reason for the presence of the FTDI port.

We could get rid of the FTDI and 8MHz crystal if we don't need Serial communication
and we don't need to debug the board anymore (i.e. for production).

## Logo

The logo of Hackuarium is present on the layer 200 and 201 in eagle. You may try
to move it by hidding all the other layers.

## CAM processing

Before submitting the PCB for manufacturing like for https://www.pcbway.com you need to 
generate the Gerber files.

The CAM processor for eagle starting 8.6 is present in this folder. They changed
completely the format but what is cool is that you can now directly export the ZIP file.
You may remove from the silk layer 200 or 201 if the logo of hackuarium really does not
fit.
Don't forget to test the generated gerber by uploading it on https://gerber-viewer.easyeda.com/

# ATmega328 pin map

| Pin | Map to | Function | Remarks
| --- | --- | --- | ---
| D0 | PD0(RXD) | RX |
| D1 | PD1(TXD) | TX |
| D2 | PD2(INT0) | | Interrupt allows wake up
| D3 | PD3(INT1) | | Interrupt allows wake up
| D4 | PD4(XCK/T0) | |
| D5 | PD5(T1) | | Counter
| D6 | PD6(AIN0) | |
| D7 | PD7(AIN1) | |
| D8 | PB0(ICP) | |
| D9 | PB1(OC1A) | | PWM
| D10 | PB2(SS/OC1B)  | | PWM
| D11 | PB3(MOSI/OC2) | MOSI |
| D12 | PB4(MISO) | MISO |
| D13 | PB5(SCK) | SCK |
| D14 A0 | PC0(ADC0) | | ADC
| D15 A1 | PC1(ADC1) | | ADC
| D16 A2 | PC2/ADC2) | | ADC
| D17 A3 | PC3(ADC3) | | ADC
| D18 A4 | PC4(ADC4/SDA) | SDA |
| D19 A5 | PC5(ADC5/SCL) | SCL |
| D20 A6 | ADC6 | | ADC only input
| D21 A7 | ADC7 | | ADC only input

Remarks
* RX, TX used for serial communication over USB (debug)
* SDA, SCL: I2C communication with master
* MOSI, MISO, SCK: boot loader

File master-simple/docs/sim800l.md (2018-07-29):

## Introduction

sim800l can be connected to an Arduino in order to transmit data on GPRS.

The library 'TinyGSMClient' seems really good and works with LilyPad USB.

We need to take care about the sim card so that the cutted edge point towards
outside of the holder !!!!

We should provide power between 3.4 and 4.4v. LiPo battery is of course optimal.
Here is the description of the connection between a master-simple and the sim800l.

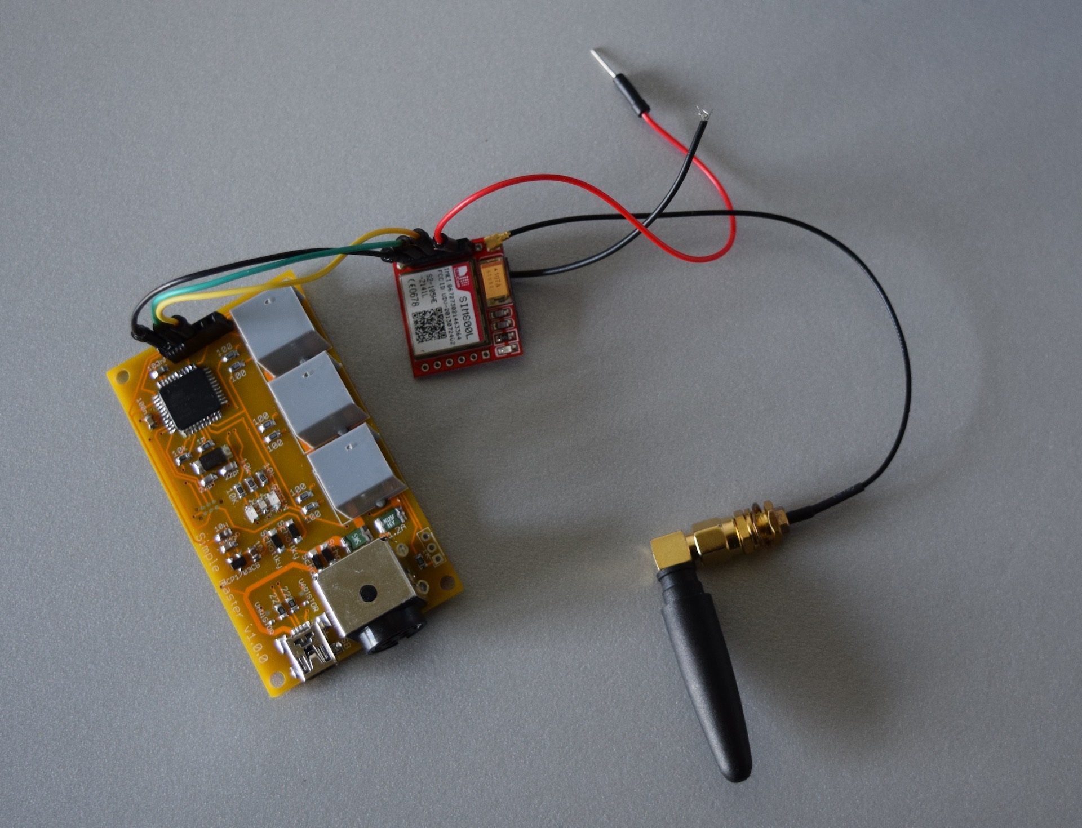
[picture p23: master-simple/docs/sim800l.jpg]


sim800l seems not to provide HTTPS. 

We have created a simple test link: http://www.cheminfo.org/hello.txt that allows to check the connection.

We still need to create a webservice to add data in the database and we didn't try yet MQTT.

## testing sim800l

* AT
* AT+CMEE=2 : Enable long debug
* AT+CFUN=1 : Enable full functionality
* AT+CFUN? : check CFUN
* AT+CPIN? : Connect without pin code
* AT+CSTT="sunrise","","" : connect to APN
* AT+CIICR : start wireless connection
* AT+COPS=? : List available networks
* AT+CIFSR : get IP address

AT+CIPSTART="TCP","ch4.chemexper.com",80
AT+CIPSEND=22
GET /test HTTP/1.0

* AT+COPS? : List connected network

## Get coordinates and date

AT+CGATT =1 // to attach GPRS.
AT+SAPBR =3,1,”CONTYPE”,”GPRS” //activate bearer profile.
AT+SAPBR =3,1,”APN”,”RCMNET”
AT+SAPBR=1,1
AT+SAPBR=2,1
AT+CIPGSMLOC=1,1 //to get gsm location, time and date.
AT+CIPGSMLOC=2,1 //to get gsm time and date
AT+SAPBR =0,1 //to deactivate bearer profile.

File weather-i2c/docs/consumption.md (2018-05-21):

In use: 6 to 8 mA

Without sensors: 6.37 mA

In sleep mode it consume 100µA

It is possible to wake up the slave based on the i2C address. In order to go to sleep the I2C line has to be set to LOW

## Testing consumption of Master / Slave

One `Master Simple` is connect to a `weather-i2c` board in order to show the sleep mode and the possibility for wake-up.

The ATmega328 has various sleep mode:
* idle
* ADC noise reduction
* extended standby
* standby
* power-save
* power-down

It is really the last mode that is the more interesting and allow to reduce dramatically the power consumption. From this mode there are various wake-up procedure and among them:
* external level interrupt on INT.0 or INT.1 (D2 and D3)
* watchdog interrupt
* 2-wire serial interface address match
* brown-out reset
* pin change interrupt

In order case we are interested to have I2C slaves that can go to sleep while still listening to their I2C address and wake-up when it match.

Like that we can have a board that consume nearly nothing, is waken up by a master, make some processing, returns the values to the master and go back to sleep.

This is what we would like to achieve with the weather station. We wake-up the  

We should therefore also prevent the other interrupts to happen like the brown-out, watchdog and pin change. You may check [this page](https://sites.google.com/site/qeewiki/books/avr-guide/external-interrupts-on-the-atmega328) for a nice explanation of interrupts. The PCINT (pin change interrupt) is managed by the register PCICR. By default (after reset) it is not enabled).

### Code for weather-i2c

```
#include "Arduino.h"
#include <avr/sleep.h>
#include <avr/power.h>
#include <avr/wdt.h>

#include <Wire.h>

void requestEvent() {}

void receiveEvent() {}

void startWireSlave() {
  Wire.begin(55);       // join i2c bus with address #55
  Wire.onReceive(receiveEvent); // register event
  Wire.onRequest(requestEvent); // register event
}

// Enters the arduino into sleep mode.
void enterSleep(void) {
  set_sleep_mode(SLEEP_MODE_PWR_DOWN);

  // turn off brown-out enable in software
  MCUCR = bit (BODS) | bit (BODSE);
  MCUCR = bit (BODS);

  ADCSRA &= ~(1 << ADEN); //Disable ADC: allows to win 80µA

  // Now enter sleep mode.
  sleep_mode();

}

void setup() {
  pinMode(2, INPUT_PULLUP); // INT.0 should not flip when sleeping
  pinMode(3, INPUT_PULLUP); // INT.1 should not flip when sleeping
  startWireSlave();
  delay(5000);
}
void loop() {
  enterSleep();
  delay(5000);
}
```

You can disable plenty of other things but we could not see any difference in power consumption:
```
  ACSR = (1 << ACD); //Disable the analog comparator
  DIDR0 = 0x3F; //Disable digital input buffers on all ADC0-ADC5 pins
  DIDR1 = (1 << AIN1D) | (1 << AIN0D); //Disable digital input buffer on AIN1/0

  power_twi_disable();
  power_spi_disable();
  power_usart0_disable(); //Needed for serial.print
  power_timer0_disable(); //Needed for delay and millis()
  power_timer1_disable();
  power_timer2_disable(); //Needed for asynchronous 32kHz operation
```

### Code for master-simple

```
#include <Wire.h>

void setup() {
  pinMode(13, OUTPUT);
  Wire.begin();
}

void loop() {
  delay(15000);
  Wire.requestFrom(55, 0);
  digitalWrite(13, HIGH);
  delay(5000);
  digitalWrite(13, LOW);
}
```

We show here that we can wake-up the slave based on the address match.

* Consumption in sleep mode: 20µA
* Consumtpion awake: 3.8mA

## Retrieving data from sleeping wire slave

A wire slave is able to listen to its address and wake up- But what about retrieving information from the sleeping slave ?

In those sketch we show that just after waking up it can actually already send back the information. This allows therefore to keep the slave awake a very short time like in this small example, 2ms.

### Code for master-simple

```
#include <Wire.h>

void setup() {
  pinMode(13, OUTPUT);
  Wire.begin();
  Serial.begin(9600);
}

void loop() {
  delay(1000);
  Wire.requestFrom(55, 1);
  byte value = Wire.read();
  Serial.println(value);
  
  digitalWrite(13, HIGH);
  delay(1000);
  digitalWrite(13, LOW);
}
```

### Code for weather-i2c

```
#include "Arduino.h"
#include <avr/sleep.h>
#include <avr/power.h>
#include <avr/wdt.h>

#include <Wire.h>

void requestEvent() {
  Wire.write(random(0,255));
}

void receiveEvent() {
  while (Wire.available()) { // loop through all but the last
    Wire.read(); // receive byte as a character
  }
}

void startWireSlave() {
  Wire.begin(55);       // join i2c bus with address #55
  Wire.onReceive(receiveEvent); // register event
  Wire.onRequest(requestEvent); // register event
}

// Enters the arduino into sleep mode.
void enterSleep(void) {
  set_sleep_mode(SLEEP_MODE_PWR_DOWN);

  // turn off brown-out enable in software
  MCUCR = bit (BODS) | bit (BODSE);
  MCUCR = bit (BODS);

  uint8_t analogStatus = ADCSRA & (1 << ADEN);
  ADCSRA &= ~(1 << ADEN); //Disable ADC: allows to win 80µA

  // Now enter sleep mode.
  sleep_mode();

  ADCSRA |= analogStatus;
}

void setup() {
  pinMode(2, INPUT_PULLUP); // INT.0 should not flip when sleeping
  pinMode(3, INPUT_PULLUP); // INT.1 should not flip when sleeping
  startWireSlave();
  delay(5000);
}
void loop() {
  enterSleep();
  delay(2);
}
```

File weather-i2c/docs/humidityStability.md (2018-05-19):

We put a random wait time (s) before turning on the DHT-22 and a random wait time (s) after turning on the device.

beforeOn: 7  afterOn: 9  Temperature: 22.40  Humidity: 48.50
beforeOn: 3  afterOn: 8  Temperature: 22.40  Humidity: 48.60
beforeOn: 0  afterOn: 2  Temperature: 22.40  Humidity: 48.50
beforeOn: 4  afterOn: 8  Temperature: 22.40  Humidity: 48.50
beforeOn: 3  afterOn: 9  Temperature: 22.40  Humidity: 49.90
beforeOn: 0  afterOn: 5  Temperature: 22.40  Humidity: 50.40
beforeOn: 2  afterOn: 2  Temperature: 22.40  Humidity: 49.80
beforeOn: 7  afterOn: 3  Temperature: 22.40  Humidity: 49.20
beforeOn: 7  afterOn: 9  Temperature: 22.40  Humidity: 49.00
beforeOn: 0  afterOn: 2  Temperature: 22.40  Humidity: 48.90
beforeOn: 3  afterOn: 9  Temperature: 22.40  Humidity: 48.80
beforeOn: 9  afterOn: 7  Temperature: 22.40  Humidity: 48.80
beforeOn: 0  afterOn: 3  Temperature: 22.40  Humidity: 48.70
beforeOn: 9  afterOn: 8  Temperature: 22.40  Humidity: 48.70
beforeOn: 6  afterOn: 5  Temperature: 22.40  Humidity: 48.70
beforeOn: 7  afterOn: 6  Temperature: 22.40  Humidity: 48.80
beforeOn: 2  afterOn: 7  Temperature: 22.40  Humidity: 48.70
beforeOn: 0  afterOn: 3  Temperature: 22.40  Humidity: 48.70
beforeOn: 9  afterOn: 9  Temperature: 22.40  Humidity: 48.70
beforeOn: 9  afterOn: 1  Temperature: 22.40  Humidity: 48.80
beforeOn: 7  afterOn: 2  Temperature: 22.40  Humidity: 48.90
beforeOn: 3  afterOn: 6  Temperature: 22.40  Humidity: 50.30
beforeOn: 5  afterOn: 5  Temperature: 22.40  Humidity: 49.70
beforeOn: 8  afterOn: 1  Temperature: 22.40  Humidity: 49.20
beforeOn: 4  afterOn: 7  Temperature: 22.40  Humidity: 49.10
beforeOn: 1  afterOn: 3  Temperature: 22.40  Humidity: 49.00
beforeOn: 8  afterOn: 4  Temperature: 22.40  Humidity: 48.90
beforeOn: 8  afterOn: 0  Temperature: 22.40  Humidity: 49.10
beforeOn: 4  afterOn: 6  Temperature: 22.40  Humidity: 49.00
beforeOn: 0  afterOn: 3  Temperature: 22.40  Humidity: 49.00
beforeOn: 2  afterOn: 6  Temperature: 22.40  Humidity: 48.90
beforeOn: 9  afterOn: 4  Temperature: 22.40  Humidity: 49.00
beforeOn: 1  afterOn: 3  Temperature: 22.40  Humidity: 48.90
beforeOn: 7  afterOn: 8  Temperature: 22.40  Humidity: 48.90
beforeOn: 8  afterOn: 3  Temperature: 22.40  Humidity: 49.40
beforeOn: 8  afterOn: 1  Temperature: 22.40  Humidity: 49.60
beforeOn: 5  afterOn: 3  Temperature: 22.40  Humidity: 49.50
beforeOn: 5  afterOn: 4  Temperature: 22.40  Humidity: 49.30
beforeOn: 3  afterOn: 6  Temperature: 22.40  Humidity: 49.20
beforeOn: 5  afterOn: 9  Temperature: 22.40  Humidity: 49.10
beforeOn: 5  afterOn: 4  Temperature: 22.40  Humidity: 49.00
beforeOn: 9  afterOn: 1  Temperature: 22.40  Humidity: 49.00
beforeOn: 7  afterOn: 5  Temperature: 22.40  Humidity: 48.90
beforeOn: 5  afterOn: 4  Temperature: 22.40  Humidity: 48.90
beforeOn: 1  afterOn: 8  Temperature: 22.40  Humidity: 48.90
beforeOn: 8  afterOn: 3  Temperature: 22.40  Humidity: 48.90
beforeOn: 5  afterOn: 2  Temperature: 22.40  Humidity: 49.10
beforeOn: 2  afterOn: 6  Temperature: 22.40  Humidity: 49.10
beforeOn: 6  afterOn: 7  Temperature: 22.40  Humidity: 49.00
beforeOn: 8  afterOn: 4  Temperature: 22.40  Humidity: 49.00
beforeOn: 1  afterOn: 7  Temperature: 22.40  Humidity: 49.00
beforeOn: 1  afterOn: 8  Temperature: 22.40  Humidity: 48.90
beforeOn: 7  afterOn: 8  Temperature: 22.40  Humidity: 48.90
beforeOn: 7  afterOn: 7  Temperature: 22.40  Humidity: 48.90
beforeOn: 4  afterOn: 4  Temperature: 22.40  Humidity: 50.50
beforeOn: 9  afterOn: 1  Temperature: 22.40  Humidity: 49.80
beforeOn: 5  afterOn: 5  Temperature: 22.40  Humidity: 49.50
beforeOn: 5  afterOn: 8  Temperature: 22.40  Humidity: 49.30
beforeOn: 2  afterOn: 9  Temperature: 22.40  Humidity: 49.80
beforeOn: 8  afterOn: 2  Temperature: 22.40  Humidity: 49.60
beforeOn: 0  afterOn: 7  Temperature: 22.40  Humidity: 50.30
beforeOn: 4  afterOn: 8  Temperature: 22.40  Humidity: 50.20
beforeOn: 5  afterOn: 8  Temperature: 22.40  Humidity: 50.00
beforeOn: 3  afterOn: 0  Temperature: 22.40  Humidity: 49.50
beforeOn: 6  afterOn: 2  Temperature: 22.40  Humidity: 49.30
beforeOn: 2  afterOn: 5  Temperature: 22.40  Humidity: 49.30
beforeOn: 2  afterOn: 2  Temperature: 22.40  Humidity: 49.20
beforeOn: 7  afterOn: 1  Temperature: 22.40  Humidity: 49.20
beforeOn: 5  afterOn: 2  Temperature: 22.40  Humidity: 49.40
beforeOn: 1  afterOn: 1  Temperature: 22.40  Humidity: 49.70
beforeOn: 0  afterOn: 1  Temperature: 22.40  Humidity: 49.60
beforeOn: 8  afterOn: 7  Temperature: 22.40  Humidity: 49.40
beforeOn: 6  afterOn: 0  Temperature: 22.40  Humidity: 49.30
beforeOn: 0  afterOn: 9  Temperature: 22.40  Humidity: 49.30
beforeOn: 5  afterOn: 6  Temperature: 22.40  Humidity: 49.10
beforeOn: 2  afterOn: 8  Temperature: 22.40  Humidity: 49.10
beforeOn: 5  afterOn: 9  Temperature: 22.40  Humidity: 49.00
beforeOn: 4  afterOn: 3  Temperature: 22.40  Humidity: 50.20
beforeOn: 9  afterOn: 0  Temperature: 22.50  Humidity: 50.50
beforeOn: 5  afterOn: 6  Temperature: 22.40  Humidity: 50.00
beforeOn: 3  afterOn: 6  Temperature: 22.40  Humidity: 49.50
beforeOn: 3  afterOn: 0  Temperature: 22.40  Humidity: 49.40
beforeOn: 8  afterOn: 4  Temperature: 22.40  Humidity: 49.30
beforeOn: 0  afterOn: 4  Temperature: 22.40  Humidity: 49.20
beforeOn: 6  afterOn: 4  Temperature: 22.40  Humidity: 50.70
beforeOn: 6  afterOn: 4  Temperature: 22.40  Humidity: 50.40
beforeOn: 3  afterOn: 8  Temperature: 22.40  Humidity: 49.90
beforeOn: 4  afterOn: 0  Temperature: 22.40  Humidity: 49.50
beforeOn: 0  afterOn: 9  Temperature: 22.40  Humidity: 49.50
beforeOn: 3  afterOn: 7  Temperature: 22.50  Humidity: 49.40
beforeOn: 5  afterOn: 7  Temperature: 22.50  Humidity: 49.30
beforeOn: 2  afterOn: 9  Temperature: 22.50  Humidity: 49.30
beforeOn: 7  afterOn: 5  Temperature: 22.40  Humidity: 49.20
beforeOn: 6  afterOn: 5  Temperature: 22.40  Humidity: 49.10
beforeOn: 3  afterOn: 0  Temperature: 22.40  Humidity: 49.10
beforeOn: 4  afterOn: 8  Temperature: 22.40  Humidity: 49.10
beforeOn: 5  afterOn: 5  Temperature: 22.40  Humidity: 49.00
beforeOn: 5  afterOn: 4  Temperature: 22.50  Humidity: 49.20
beforeOn: 2  afterOn: 1  Temperature: 22.50  Humidity: 49.20
beforeOn: 9  afterOn: 2  Temperature: 22.40  Humidity: 49.00
beforeOn: 4  afterOn: 5  Temperature: 22.40  Humidity: 49.00
beforeOn: 8  afterOn: 6  Temperature: 22.40  Humidity: 49.00
beforeOn: 2  afterOn: 5  Temperature: 22.40  Humidity: 49.00

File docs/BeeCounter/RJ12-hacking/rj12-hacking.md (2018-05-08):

# Connector for luminosity, temperature and power supply

The default connector as the following pin out

* +12V (not connected)
* SCL (PWM)
* SDA (I/O)
* A6 (GND)
* +5V
* GND

There is the possiblity to have an internal pullup so that if we connect a LDR between the ground and A6 it should be possible to measure the light intensity.

We can also connect a one-wire temperature probe DS18B20 connected to SCL. We will also have to connect a 4.7kΩ between +5V and SCL.

Finally we can connect the power supply between the +5V and the GND. The power supply may be anything between 3.7 and 6V.

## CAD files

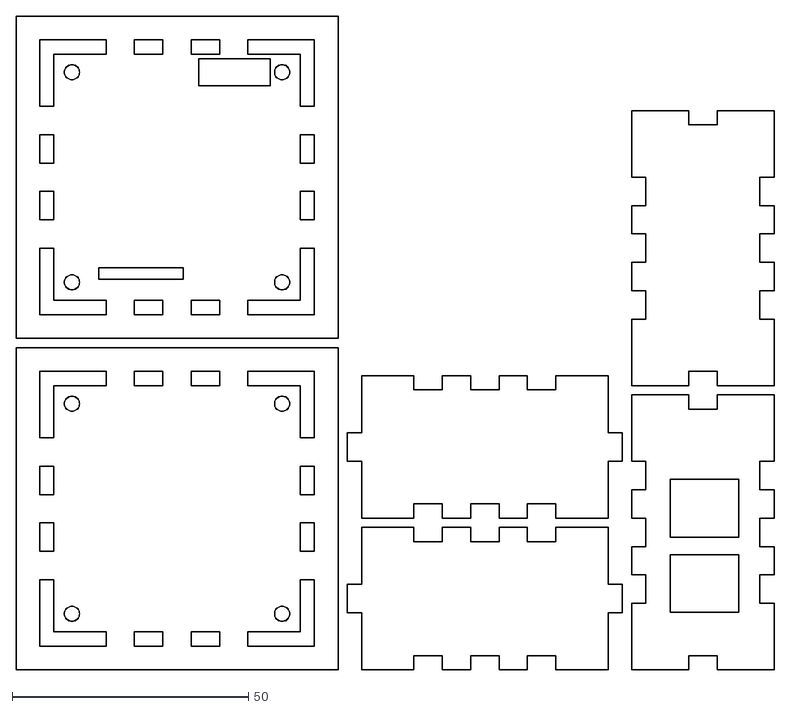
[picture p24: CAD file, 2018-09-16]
scale-i2c/cad/box_scale.dxf
160.4 x 138.3

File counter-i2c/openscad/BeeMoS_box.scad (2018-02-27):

	  boardLength=127;      // including USB port protruding 
	  boardWidth=32;
	  boardHeight=6;
	  wallThickness=3;      // including USB port protruding
	  IRLength=5;         // individual IR emitter/receiver measurements including IC legs
	  IRWidth=4;          // 
	  IRHeight=2;
	  xSpaceBetweenGates=13;
	  ySpaceBetweenGates=9;
	  

	 module get_board_vol(){  
	 //Estimates the volume of the cuboid needed to fit the board in red (taking max values for height so that the USB port has enough space), space for IR sensors (bottom of board) are in yellow 
	
	      color("red")
	      cube([boardLength,boardWidth,boardHeight],center=true);
	      // make 8 yellow IR sensors
	      translate([-32,-2.5,0]) // positioning of the 8 gates
	      get_8_gates();
	      translate([-32,-2.5-ySpaceBetweenGates,0]) // positioning of the 8 gates
	      get_8_gates();	      

	      }
	module get_8_gates(){
	        for (i=[0:7])
	      translate([boardLength/2-0.5-xSpaceBetweenGates*i,boardWidth/2-0.5,boardHeight/2+0.5])
	      color("yellow")
	      cube([IRLength,IRWidth,IRHeight],center=true);
	    }
	
	get_board_vol();
translate([-4,0,0]){
   difference(){
   color("orange")
	translate([0,0,20])
	cube([boardLength+2+8,boardWidth+2,8],center=true);
   color("blue")
	translate([0,0,22])
	cube([boardLength+8,boardWidth,7],center=true);
	}
}

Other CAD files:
counter-i2c/freecad/counterBox_v6.FCstd
master/freecad/enclosure_scale_master.fcstd

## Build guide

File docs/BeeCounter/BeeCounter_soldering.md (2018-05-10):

# BeeMos bee counter module (BCM) documentation
## BCM PCB soldering and debug instructions (_UNDER CONSTRUCTION_)



### 1. Solder the basic elements to make the microcontroller work as shown in the picture above in red (starting with the hardest/riskiest to solder):
* Microcontroller
* Mini USB port
* Voltage regulator
* 2x 22 Ohm resistors
* 3x 10 uF capacitors 
* 3x Shottky diodes (direction matters)
* 4x 10k Ohm resistors 
* 3x 100 nF capacitors
* 1M F capacitor
* 2x 22 pF capacitors
* 8 Mhz cristal
* Blank/white LED (direction matters)
* Red LED (direction matters)

### 2. Power the board by connecting the USB cable (one LED should turn on), check immediately that the USB port or the microcontroller are not overheating by touching them with your fingers (a few seconds are usually enough to know)
### 3. Choose "Lilipad USB" as board in the Arduino IDE, then burn bootloader with USBtiny in-circuit programmer and JTAG cable in contact with the ISP pins of the board until the bootloader has finished to burn
### 4. Connect the board to computer with USB cable, upload a simple "blink" sketch, confirm that the sketch was indeed uploaded (i.e. confirm that the LED is indeed blinking)
### 5. Disconnect the USB cable and solder the demultiplexer, the multiplexer and 1 IR emitter/receptor (QRE1113) as shown in blue in the above picture. Try not to spend to much time while soldering to avoid overheating of the component. Solder the two associated resistors (see note below before doing so). 
### *IMPORTANT: in PCB version 1.0, the two resistors are labelled "220" and "1k", DO NOT USE THIS VALUES.* Use 100 Ohm instead of 1 kOhm and 1 kOhm instead of 220 Ohm.  
### 6. *IR LED emission test*: Reconnect the USB cable, choose the Lilipad USB as board (Tools => Board => Lilipad USB), select the port where it is connected (this should appear under Tools => Ports as ttyACM0 (Lilipad USB) ), upload the Arduino sketch and check that the IR LED is emitting either using an oscilloscope between  ~~pins X and Y~~ or by using the camera of your phone (you should see a purple beam, although this works more or less depending on your phone/camera, you can try to go in a dark place to better see the IR beam). In case you see no signal from the IR LED, make sure soldering is appropriate and if fiddling with soldering doesn't work, try replacing the QRE1113 sensor (some have failed  during our test perhaps due to overheating during soldering or manufacture issues)
### 7. Disconnect USB cable and solder the 15 other QRE1113s, their associated resistors and the RJ12 connector as indicated in yellow in the above image.
### 8. Repeat the IR LED emission test (from step 6) on all other QRE1113s until all work
### 9. To test the board, connect the USB cable, open the serial monitor in Arduino IDE and make sure to choose the "Both NL & CR" option at the bottom right of the serial monitor (needed to have access to the menu). Pressing "h" (for "help") + ENTER will show you the different menus you can enter by typing the first letter + ENTER. Try "c" + ENTER to see the hexadecimal values of the IR values read from the sensors: when passing your finger or a pencil over a sensor, you should see its corresponding value change. "s" + ENTER will display setting A to Z. A is the log ID, B the number of seconds since the card was started, then C and D are respectively the number of exiting and entering bees through gate 1, E and F the number of exiting and entering bees through gate 2 etc. You can move a pencil over a gate in both direction and retype 's'+ENTER to update the values on the serial monitor screen.
### 10. Install the PCB in its laser cut box
### 11. Test in the field

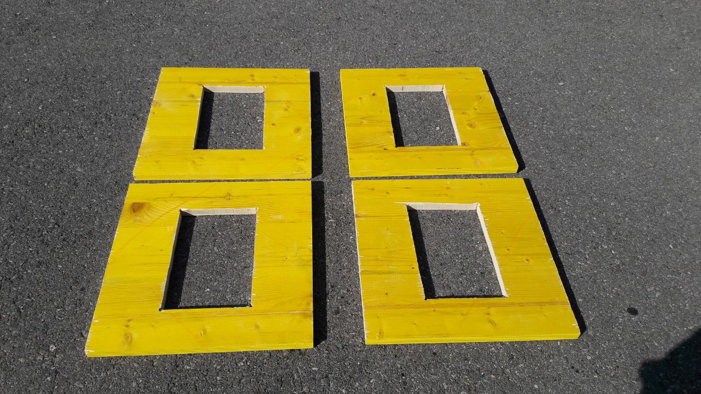
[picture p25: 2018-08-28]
scale-i2c/docs/balance2&3Disassembled.jpg

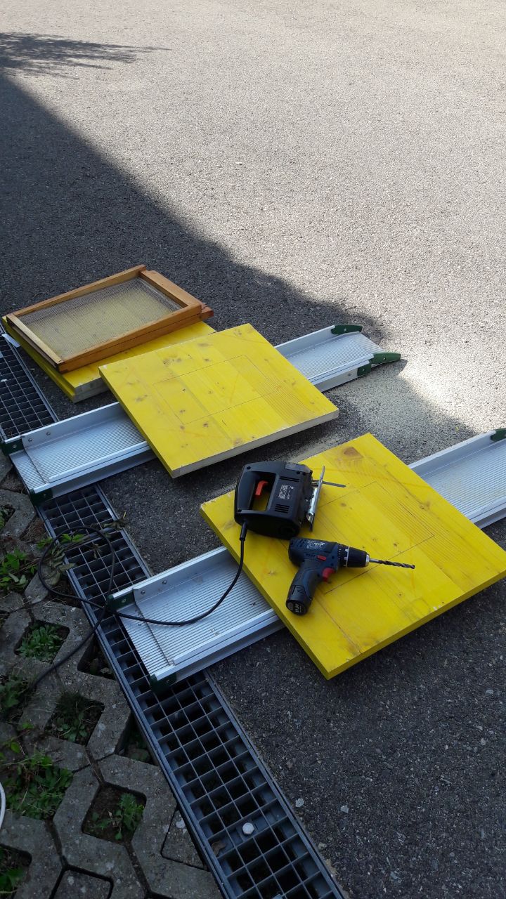
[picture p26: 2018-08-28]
scale-i2c/docs/balance2&3Construction.jpg

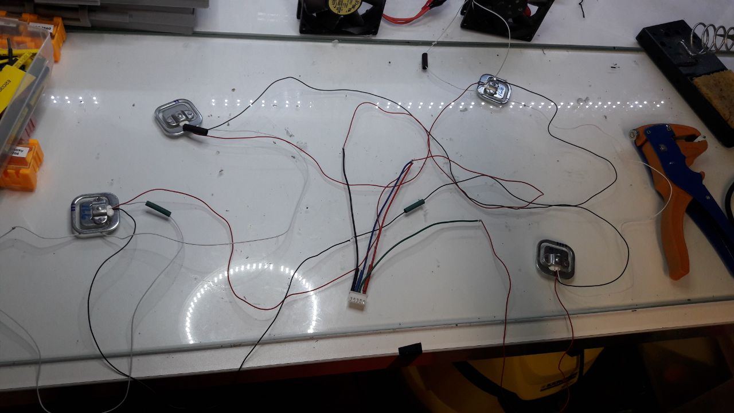
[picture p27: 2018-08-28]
scale-i2c/docs/loadCellsSoldered.jpg

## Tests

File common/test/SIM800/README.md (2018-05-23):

## Test GPRS connection

From [https://elementztechblog.wordpress.com/2017/09/16/getting-location-from-gsm/](https://elementztechblog.wordpress.com/2017/09/16/getting-location-from-gsm/)

```
AT+CGATT =1 // to attach GPRS.

AT+SAPBR =3,1,”CONTYPE”,”GPRS” //activate bearer profile.

AT+SAPBR =3,1,”APN”,”RCMNET”

AT+SAPBR=1,1

AT+SAPBR=2,1

AT+CIPGSMLOC=1,1 //to get gsm location, time and date.

AT+CIPGSMLOC=2,1 //to get gsm time and date

AT+SAPBR =0,1 //to deactivate bearer profile.
```

## Retrieve IP address

* `AT+SAPBR=2,1`

## Location and time

[You may check this video](https://www.youtube.com/watch?v=ohygu1D0SN8)

It should be possibl eto retrieve infomraiton aobut the location and the time directly
from the GPRS data using the command `AT+CIPGSMLOC`.

* `AT+CIPGSMLO=1,1` to retrieve the time
* `AT+CIPGSMLO=2,1` to retrieve the location

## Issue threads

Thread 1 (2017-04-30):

Counter

lpatiny, 2017-04-30:
* analogic multiplexer - CD74HC4067 * 3 : 7 pins for selection + 3 AD - http://www.ti.com/lit/ds/symlink/cd74hc4067.pdf
* QRE1113 emitter / receiver IR: 48
* CD54HC154 decoder - demultiplexer: 7 pins

* I2C : 2 pins

lpatiny, 2018-05-19:
PCB was done and works correctly.

Closed 2018-05-19.

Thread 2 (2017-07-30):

Add a sound detectior

lpatiny, 2017-07-30:
Get inspired by amplification of :
https://www.arduino.cc/en/Tutorial/SimpleAudioFrequencyMeter

Use pin D6 to be able to use the internal counter

lpatiny, 2017-07-30:
Amplification could be controlled using a digital potentiometer

http://www.instructables.com/id/Digital-Potentiometer-MCP41100-and-Arduino/

lpatiny, 2017-07-30:
mcp41100 was ordered on ebay

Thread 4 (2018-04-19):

Meteostation

cmdoret, 2018-04-19:
Slave ATMEGA328

Slave I2C:

- https://github.com/lpatiny/legoino/tree/master/eagle/halloween/halloween2013/led-driver

LDR: Spectro board for pot

 - https://github.com/opatiny/stea-mp-unk-3/tree/master/eagle/cardReader
 - pin analogique

One wire:

 - 18B20
 - https://www.diymodules.org/eagle-show-object?type=usr&id=2575&device=DS18B20

DHT22

Pressure:

 - https://www.mouser.ch/datasheet/2/418/NG_DS_MS5637-02BA03_B1-1130139.pdf
 - on 2 pins to make software wire (I2C) (not SCL and SDA)
 - or pressure sensor that use another protocol

lpatiny, 2018-08-28:
Done

Closed 2018-08-28.

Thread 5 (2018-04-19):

Add also pressure sensor ?

cmdoret, 2018-04-19:
But it will be difficult to solder ...

http://www.te.com/commerce/DocumentDelivery/DDEController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

Closed 2018-04-23.

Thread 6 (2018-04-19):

Module for GSM transmission

cmdoret, 2018-04-19:
https://exploreembedded.com/wiki/GSM_SIM800L_Sheild_with_Arduino

lpatiny, 2018-08-29:
Master board has the socket for SIM800l

Closed 2018-08-29.

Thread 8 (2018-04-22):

move all the slaves in slaves-i2c

lpatiny, 2018-04-22:
@cmdoret you could also rename it to slave maybe

cmdoret, 2018-04-22:
Done, there is also a "master" board and a "mainboard". Not sure about the distinction between  the two. I think one should be removed.

lpatiny, 2018-04-22:
Yes I think there could be a 'master' folder containing 2 projects. @oliemery you could create one more level 'master' and migrate your code inside this new folder (as well as the 'master-simple' that could be renamed 'simple'

lpatiny, 2018-05-19:
We will probably still refactor the project ...

Closed 2018-05-19.

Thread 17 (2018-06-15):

Format + complete PCB README

cmdoret, 2018-06-15:
I just linked individual README files into the [github-pages website](https://hackuarium.github.io/beemos/).
We should ensure each README is complete and has a consistent formatting

- Each README should be in beemos/board-name/README.md

- [ ] counter-i2c

- [ ] master-simple

- [ ] scale-i2c

- [ ] weather-i2c

- They should have well defined sections (e.g. Description, Components, Performances)

- [ ] counter-i2c

- [ ] master-simple

- [ ] scale-i2c

- [ ] weather-i2c

- They should include a link to the main github-pages website at the top

- [ ] counter-i2c

- [ ] master-simple

- [ ] scale-i2c

- [ ] weather-i2c

cmdoret, 2018-06-15:
Should we add pictures of the boards in the READMEs ?

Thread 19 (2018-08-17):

counter: allow to turn off the leds to prevent the blank cycle

lpatiny, 2018-08-17:

Closed 2018-08-28.

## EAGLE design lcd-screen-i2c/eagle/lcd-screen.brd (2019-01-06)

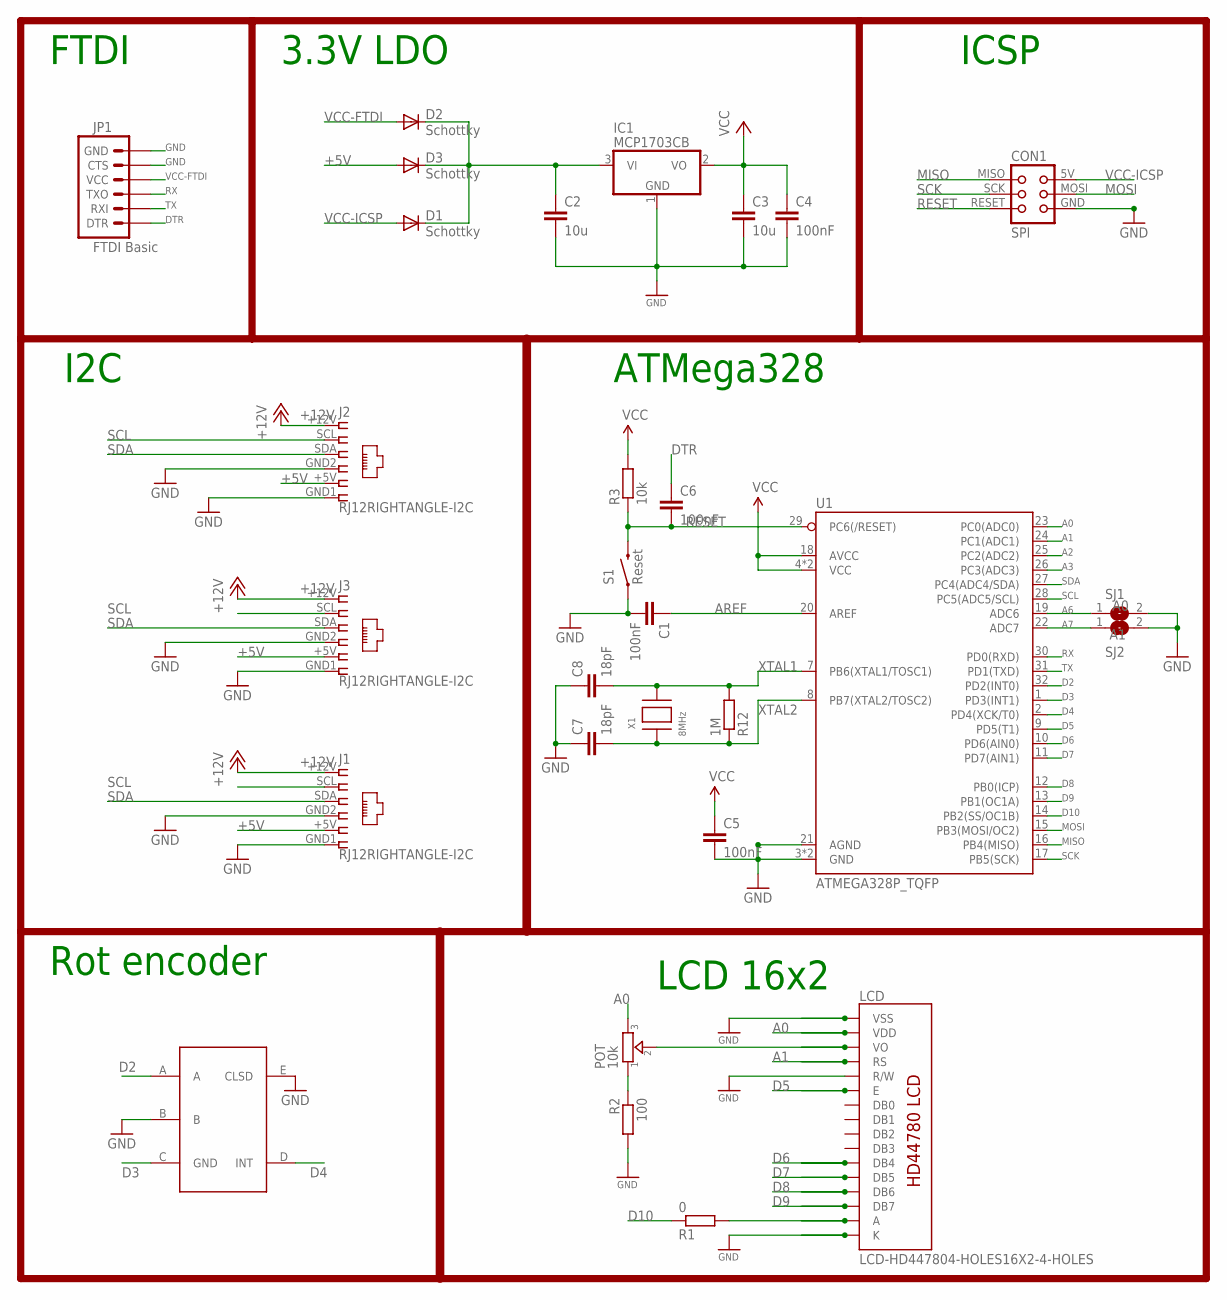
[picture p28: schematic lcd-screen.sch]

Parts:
C1, C4, C5, C6: 100nF; C0805K; MPN 80-C1206C104K5R; LCSC C49678
C2, C3: 10u; C0805K; MPN 77-VJ1206V106ZXQTBC; LCSC C15850
C7, C8: 18pF; C0805K; MPN 77-VJ1206A180JXXPBC; LCSC C1797
CON1: SPI; TC2030-MCP
D1, D2, D3: Schottky; SOD123; MPN 621-1N5819HW-F; LCSC C82544
IC1: MCP1703CB; SOT23; LCSC C53352
J1, J2, J3: RJ12RIGHTANGLE-I2C; RJ12-RIGHTANGLE-I2C
JP1: FTDI Basic; 1X06
LCD: LCD-HD447804-HOLES16X2-4-HOLES; LCD-16X2-4HOLES
POT: 10k; TRIMMER_3362P
R1: 0; R0805; LCSC C17477
R2: 100; R0805; LCSC C17408
R3: 10k; R0805; LCSC C17513
R12: 1M; R0805; LCSC C17514
S1: Reset; TACTILE-SWITCH-SMD-ALT01
SJ1: A0; SJ
SJ2: A1; SJ
U1: ATMEGA328P_TQFP; TQFP32-08
U$1: EC11E
X1: 8MHz; NX6035; MPN 729-F60800010; LCSC C122522

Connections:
+5V: D3.A, J1.+5V (5), J2.+5V (5), J3.+5V (5)
+12V: J1.+12V (1), J2.+12V (1), J3.+12V (1)
+XV: C2.1, D1.C, D2.C, D3.C, IC1.3 (VI)
A0: LCD.2 (VDD), POT.3, U1.23 (PC0(ADC0))
A1: LCD.4 (RS), U1.24 (PC1(ADC1))
A2: U1.25 (PC2(ADC2))
A3: U1.26 (PC3(ADC3))
A6: SJ1.1, U1.19 (ADC6)
A7: SJ2.1, U1.22 (ADC7)
AREF: C1.1, U1.20 (AREF)
D2: U1.32 (PD2(INT0)), U$1.A
D3: U1.1 (PD3(INT1)), U$1.C (GND)
D4: U1.2 (PD4(XCK/T0)), U$1.D (INT)
D5: LCD.6 (E), U1.9 (PD5(T1))
D6: LCD.11 (DB4), U1.10 (PD6(AIN0))
D7: LCD.12 (DB5), U1.11 (PD7(AIN1))
D8: LCD.13 (DB6), U1.12 (PB0(ICP))
D9: LCD.14 (DB7), U1.13 (PB1(OC1A))
D10: R1.1, U1.14 (PB2(SS/OC1B))
DTR: C6.1, JP1.1 (DTR)
GND: C1.2, C2.2, C3.2, C4.2, C5.2, C7.1, C8.1, CON1.GND, IC1.1 (GND), J1.GND1 (6), J1.GND2 (4), J2.GND1 (6), J2.GND2 (4), J3.GND1 (6), J3.GND2 (4), JP1.5 (CTS), JP1.6 (GND), LCD.1 (VSS), LCD.5 (R/W), LCD.16 (K), R2.2, S1.1, S1.2 (1), SJ1.2, SJ2.2, U1.3 (GND), U1.5 (GND), U1.21 (AGND), U$1.B, U$1.E (CLSD)
MISO: CON1.MISO, U1.16 (PB4(MISO))
MOSI: CON1.MOSI, U1.15 (PB3(MOSI/OC2))
unnamed: LCD.3 (VO), POT.2
unnamed: POT.1, R2.1
unnamed: LCD.15 (A), R1.2
RESET: C6.2, CON1.RESET, R3.1, S1.3 (2), S1.4 (2), U1.29 (PC6(/RESET))
RX: JP1.3 (TXO), U1.30 (PD0(RXD))
SCK: CON1.SCK, U1.17 (PB5(SCK))
SCL: J1.SCL (2), J2.SCL (2), J3.SCL (2), U1.28 (PC5(ADC5/SCL))
SDA: J1.SDA (3), J2.SDA (3), J3.SDA (3), U1.27 (PC4(ADC4/SDA))
TX: JP1.2 (RXI), U1.31 (PD1(TXD))
VCC: C3.1, C4.1, C5.1, IC1.2 (VO), R3.2, U1.4 (VCC), U1.6 (VCC), U1.18 (AVCC)
VCC-FTDI: D2.A, JP1.4 (VCC)
VCC-ICSP: CON1.5V (VCC), D1.A
XTAL1: C8.2, R12.2, U1.7 (PB6(XTAL1/TOSC1)), X1.P$2
XTAL2: C7.2, R12.1, U1.8 (PB7(XTAL2/TOSC2)), X1.P$1

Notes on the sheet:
ICSP
ATMega328
3.3V LDO
I2C
FTDI
LCD 16x2
Rot encoder

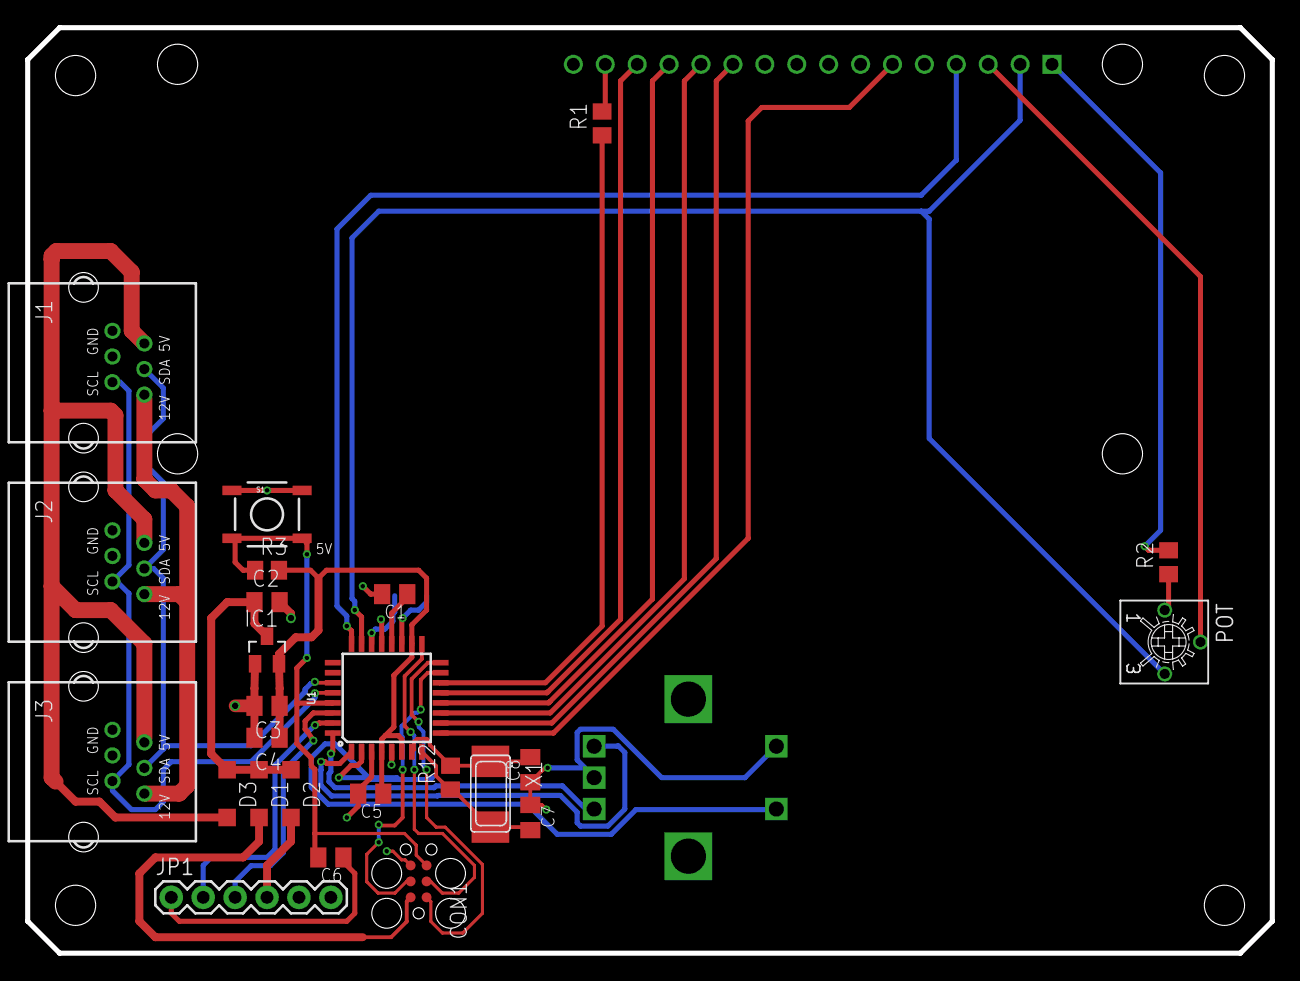
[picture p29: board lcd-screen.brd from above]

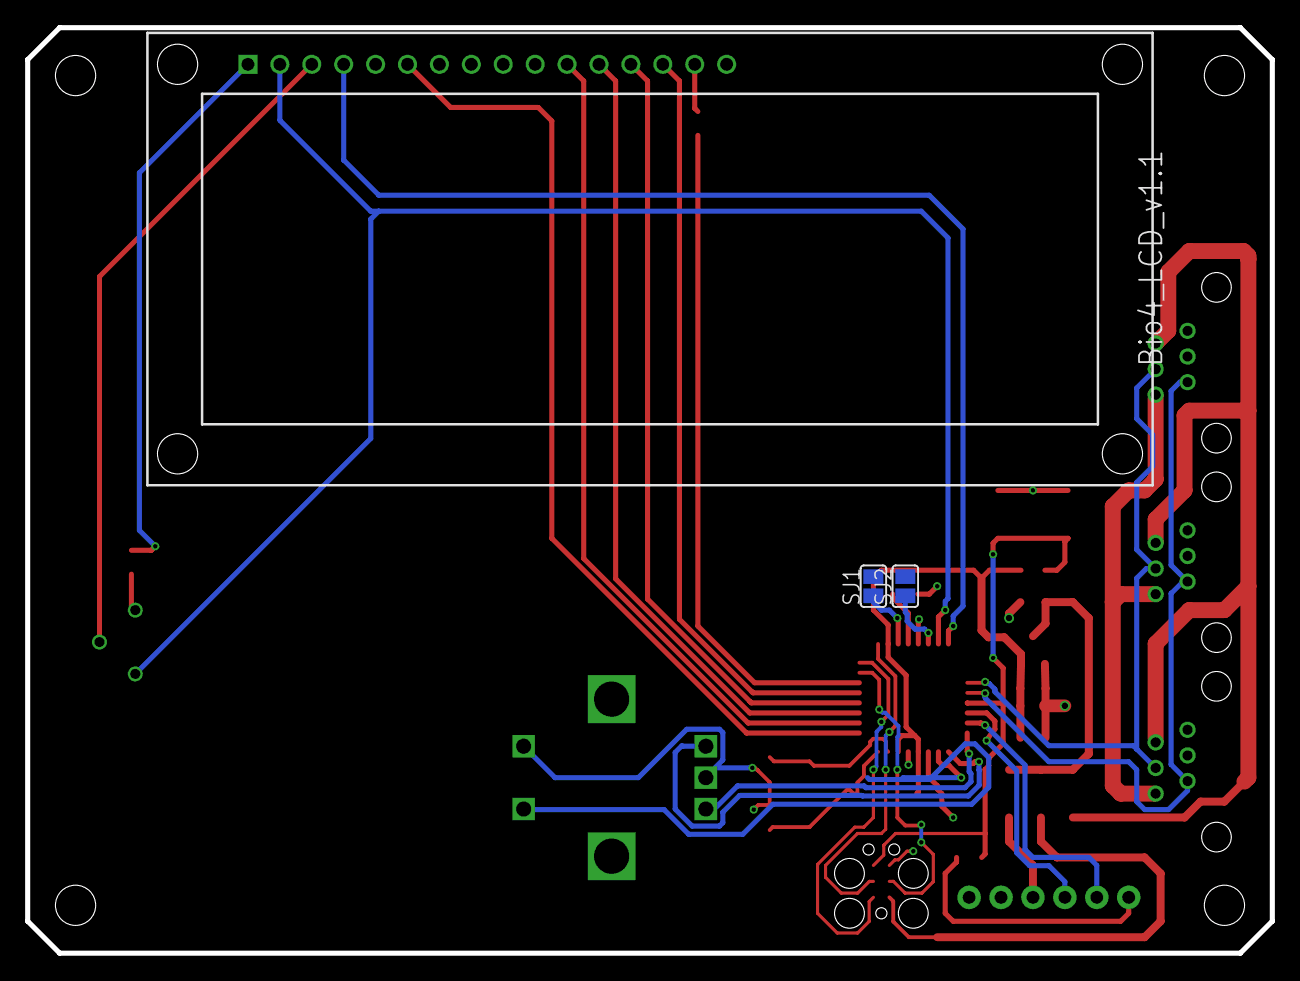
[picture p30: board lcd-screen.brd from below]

Board: 2 copper layers, 99.1 x 73.7 mm, 29 parts (4 on the bottom side), 35 nets.

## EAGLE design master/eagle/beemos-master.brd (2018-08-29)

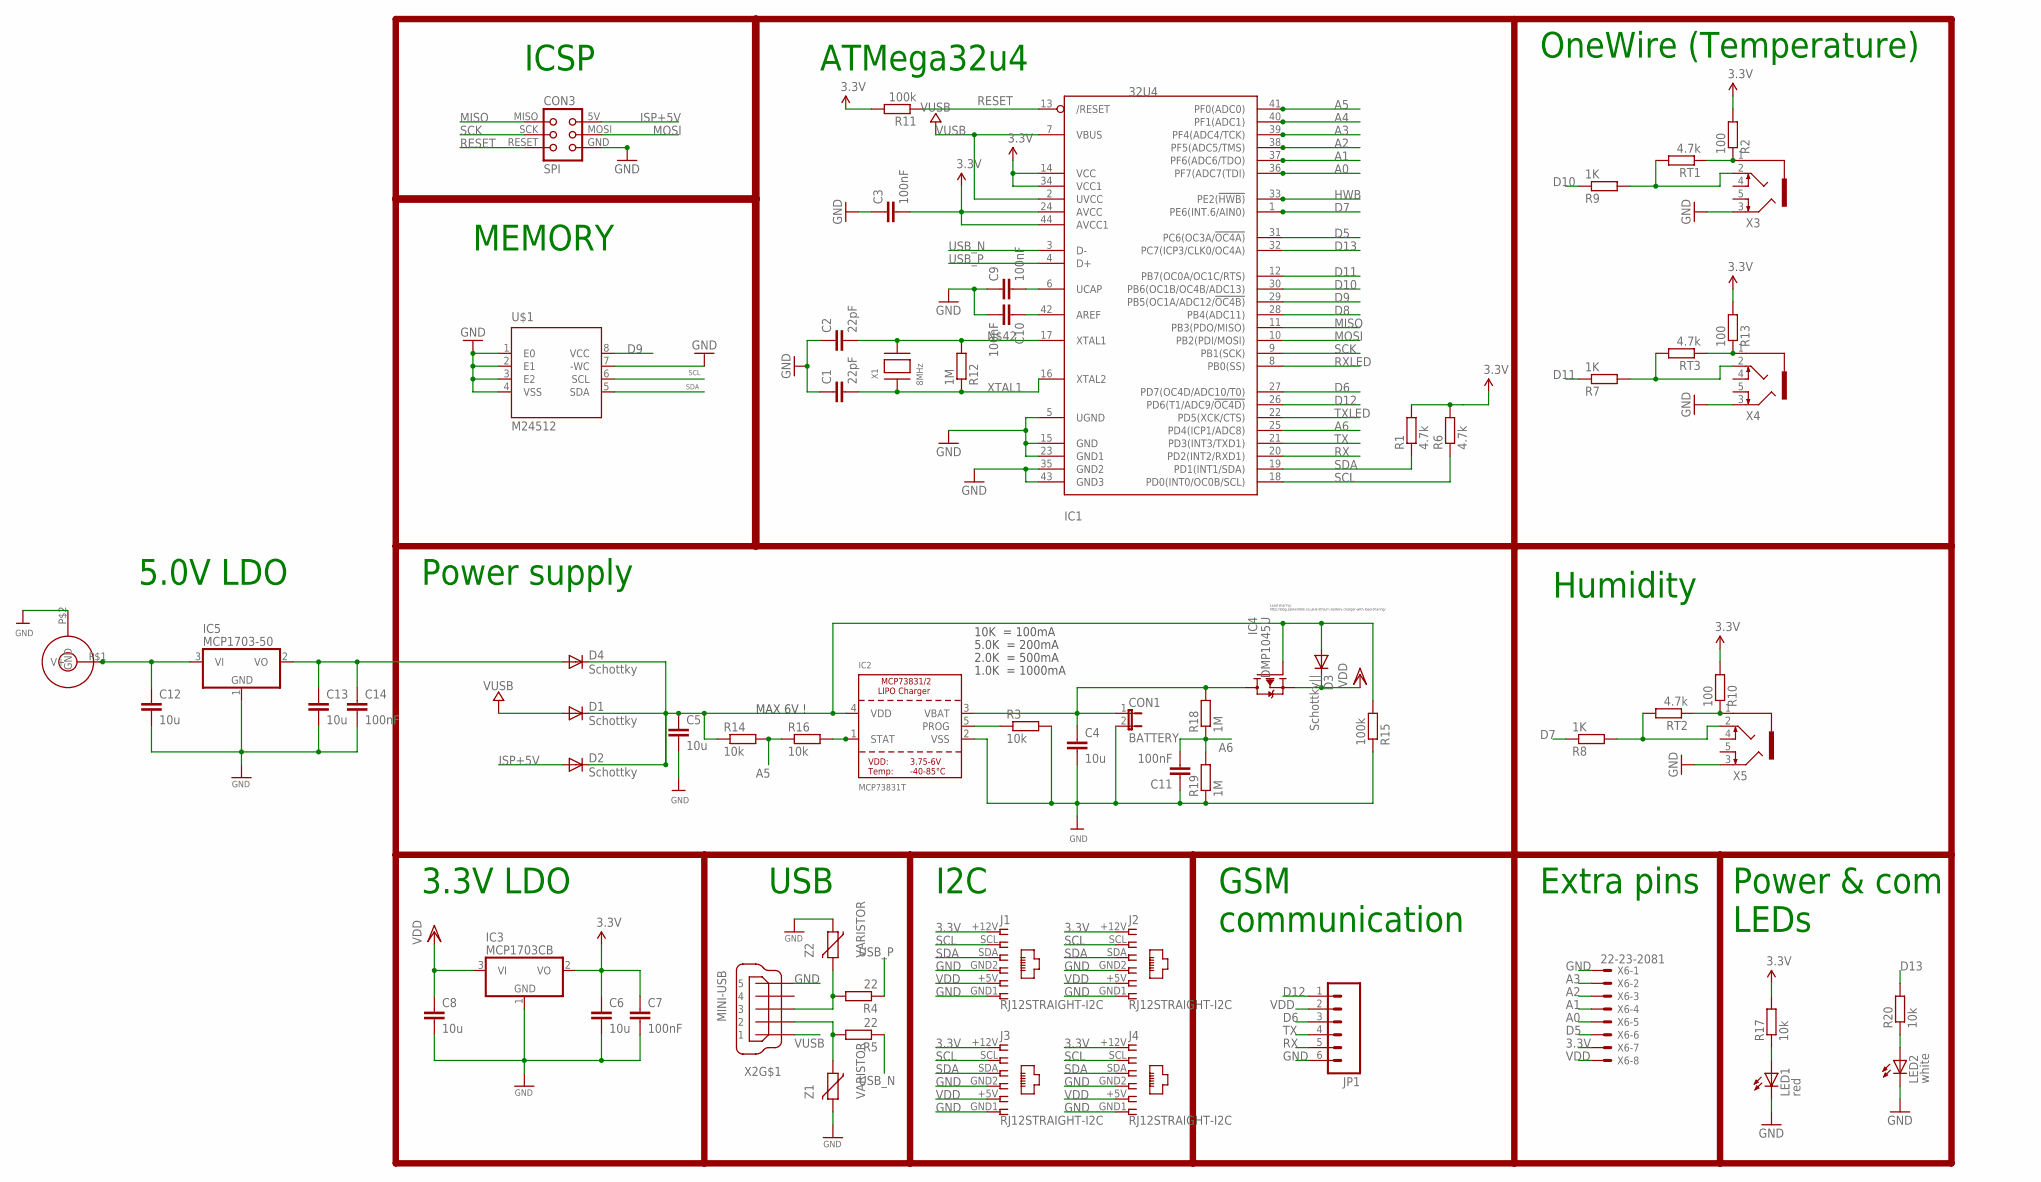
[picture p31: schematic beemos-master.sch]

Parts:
C1, C2: 22pF; C0805K; MPN 77-VJ1206A180JXXPBC; LCSC C1797
C3, C7, C9, C10, C11, C14: 100nF; C0805K; MPN 80-C1206C104K5R; LCSC C49678
C4, C5, C6, C8, C12, C13: 10u; C0805K; MPN 77-VJ1206V106ZXQTBC; LCSC C15850
CON1: BATTERY; JP1
CON2: JACK_DC_BARREL; DC_BARREL
CON3: SPI; TC2030-MCP-NL
D1, D2, D4: Schottky; SOD123; MPN 621-1N5819HW-F; LCSC C82544
D3: Schottky||; SOD123; MPN 621-1N5819HW-F; LCSC C82544
IC1: 32U4; TQFP44; MPN 556-ATMEGA32U4RC-AU; LCSC C44854
IC2: MCP73831T; SOT23-5; MPN 579-MCP73831T-3ACIOT; LCSC C14879
IC3: MCP1703CB; SOT23; LCSC C53352
IC4: DMP1045U; SOT-23; MPN 621-DMP1045U-7; LCSC C96613
IC5: MCP1703-50; SOT23
J1, J2, J3, J4: RJ12STRAIGHT-I2C; RJ12-STRAIGHT-I2C
JP1: M06RA; MOLEX-1X6-RA
LED1: red; CHIP-LED0805
LED2: white; CHIP-LED0805
R1, R6: 4.7k; R0805
R2, R10, R13: 100; R0805
R3: 10k; R0805; LCSC C17414
R4, R5: 22; R0805; LCSC C17561
R7, R8, R9: 1K; R0805
R11, R15: 100k; R0805; MPN RC1206FR-07100KL; LCSC C17407
R12, R18, R19: 1M; R0805; LCSC C17514
R14, R16: 10k; R0805; LCSC C17513
R17, R20: 10k; R0805
RT1, RT2, RT3: 4.7k; R0805
U$1: M24512; SO8
X1: 8MHz; NX6035; MPN 729-F60800010; LCSC C122522
X2: MINI-USB; 32005-201; MPN 649-10033526-N3212LF; LCSC C46391
X3, X4, X5: 1503_09
X6: 22-23-2081
Z1, Z2: VARISTOR; CT/CN0805; LCSC C79709

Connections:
3.3V: C3.2, C6.1, C7.1, IC1.14 (VCC), IC1.24 (AVCC), IC1.34 (VCC1), IC1.44 (AVCC1), IC3.2 (VO), J1.+12V (1), J2.+12V (1), J3.+12V (1), J4.+12V (1), R1.2, R2.2, R6.2, R10.2, R11.2, R13.2, R17.2, X6.7
A0: IC1.36 (PF7(ADC7(TDI)), X6.5
A1: IC1.37 (PF6(ADC6/TDO)), X6.4
A2: IC1.38 (PF5(ADC5/TMS)), X6.3
A3: IC1.39 (PF4(ADC4/TCK)), X6.2
A4: IC1.40 (PF1(ADC1))
A5: IC1.41 (PF0(ADC0)), R14.2, R16.1
A6: C11.2, IC1.25 (PD4(ICP1/ADC8)), R18.1, R19.2
AREF: C10.1, IC1.42 (AREF)
D5: IC1.31 (PC6(OC3A/!OC4A)), X6.6
D6: IC1.27 (PD7(OC4D/ADC10/T0)), JP1.3
D7: IC1.1 (PE6(INT.6/AIN0)), R8.1
D8: IC1.28 (PB4(ADC11))
D9: IC1.29 (PB5(OC1A/ADC12/!OC4B)), U$1.8 (VCC)
D10: IC1.30 (PB6(OC1B/OC4B/ADC13)), R9.1
D11: IC1.12 (PB7(OC0A/OC1C/RTS)), R7.1
D12: IC1.26 (PD6(T1/ADC9/!OC4D)), JP1.1
D13: IC1.32 (PC7(ICP3/CLK0/OC4A)), R20.2
GND: C1.1, C2.1, C3.1, C4.2, C5.2, C6.2, C7.2, C8.2, C9.1, C10.2, C11.1, C12.2, C13.2, C14.2, CON1.2, CON2.P$2 (GND), CON3.GND, IC1.5 (UGND), IC1.15 (GND), IC1.23 (GND1), IC1.35 (GND2), IC1.43 (GND3), IC2.2 (VSS), IC3.1 (GND), IC5.1 (GND), J1.GND1 (6), J1.GND2 (4), J2.GND1 (6), J2.GND2 (4), J3.GND1 (6), J3.GND2 (4), J4.GND1 (6), J4.GND2 (4), JP1.6, LED1.C, LED2.C, R3.2, R15.1, R19.1, U$1.1 (E0), U$1.2 (E1), U$1.3 (E2), U$1.4 (VSS), U$1.7 (-WC), X2.5, X3.3, X4.3, X5.3, X6.1, Z1.2, Z2.1
HWB: IC1.33 (PE2(!HWB))
ISP+5V: CON3.5V (VCC), D2.A
MISO: CON3.MISO, IC1.11 (PB3(PDO/MISO))
MOSI: CON3.MOSI, IC1.10 (PB2(PDI/MOSI))
unnamed: C9.2, IC1.6 (UCAP)
unnamed: R7.2, RT3.2, X4.2
unnamed: C13.1, C14.1, D4.A, IC5.2 (VO)
unnamed: R13.1, RT3.1, X4.1
unnamed: C5.1, D1.C, D2.C, D3.A, D4.C, IC2.4 (VDD), IC4.1 (G), R14.1, R15.2
unnamed: IC2.5 (PROG), R3.1
unnamed: IC2.1 (STAT), R16.2
unnamed: R8.2, RT2.2, X5.2
unnamed: R10.1, RT2.1, X5.1
unnamed: LED1.A, R17.1
unnamed: LED2.A, R20.1
unnamed: C12.1, CON2.P$1 (V+), IC5.3 (VI)
unnamed: R2.1, RT1.1, X3.1
unnamed: R9.2, RT1.2, X3.2
unnamed: C2.2, IC1.17 (XTAL1), R12.2, X1.P$2
RESET: CON3.RESET, IC1.13 (/RESET), R11.1
RX: IC1.20 (PD2(INT2/RXD1)), JP1.5
RXLED: IC1.8 (PB0(SS))
SCK: CON3.SCK, IC1.9 (PB1(SCK))
SCL: IC1.18 (PD0(INT0/OC0B/SCL)), J1.SCL (2), J2.SCL (2), J3.SCL (2), J4.SCL (2), R6.1, U$1.6 (SCL)
SDA: IC1.19 (PD1(INT1/SDA)), J1.SDA (3), J2.SDA (3), J3.SDA (3), J4.SDA (3), R1.1, U$1.5 (SDA)
TX: IC1.21 (PD3(INT3/TXD1)), JP1.4
TXLED: IC1.22 (PD5(XCK/CTS))
USBC_N: R5.2, X2.2, Z1.1
USBC_P: R4.2, X2.3, Z2.2
USB_N: IC1.3 (D-), R5.1
USB_P: IC1.4 (D+), R4.1
VBAT1: C4.1, CON1.1, IC2.3 (VBAT), IC4.3 (D), R18.2
VDD: C8.1, D3.C, IC3.3 (VI), IC4.2 (S), J1.+5V (5), J2.+5V (5), J3.+5V (5), J4.+5V (5), JP1.2, X6.8
VUSB: D1.A, IC1.2 (UVCC), IC1.7 (VBUS), X2.1
XTAL1: C1.2, IC1.16 (XTAL2), R12.1, X1.P$1

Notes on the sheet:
USB
ICSP
ATMega32u4
3.3V LDO
10K = 100mA
5.0K = 200mA
2.0K = 500mA
1.0K = 1000mA
MAX 6V !
Load sharing: http://blog.zakkemble.co.uk/a-lithium-battery-charger-with-load-sharing/
I2C
Power supply
OneWire (Temperature)
MEMORY
GSM communication
Humidity
Extra pins
Power & com LEDs
5.0V LDO

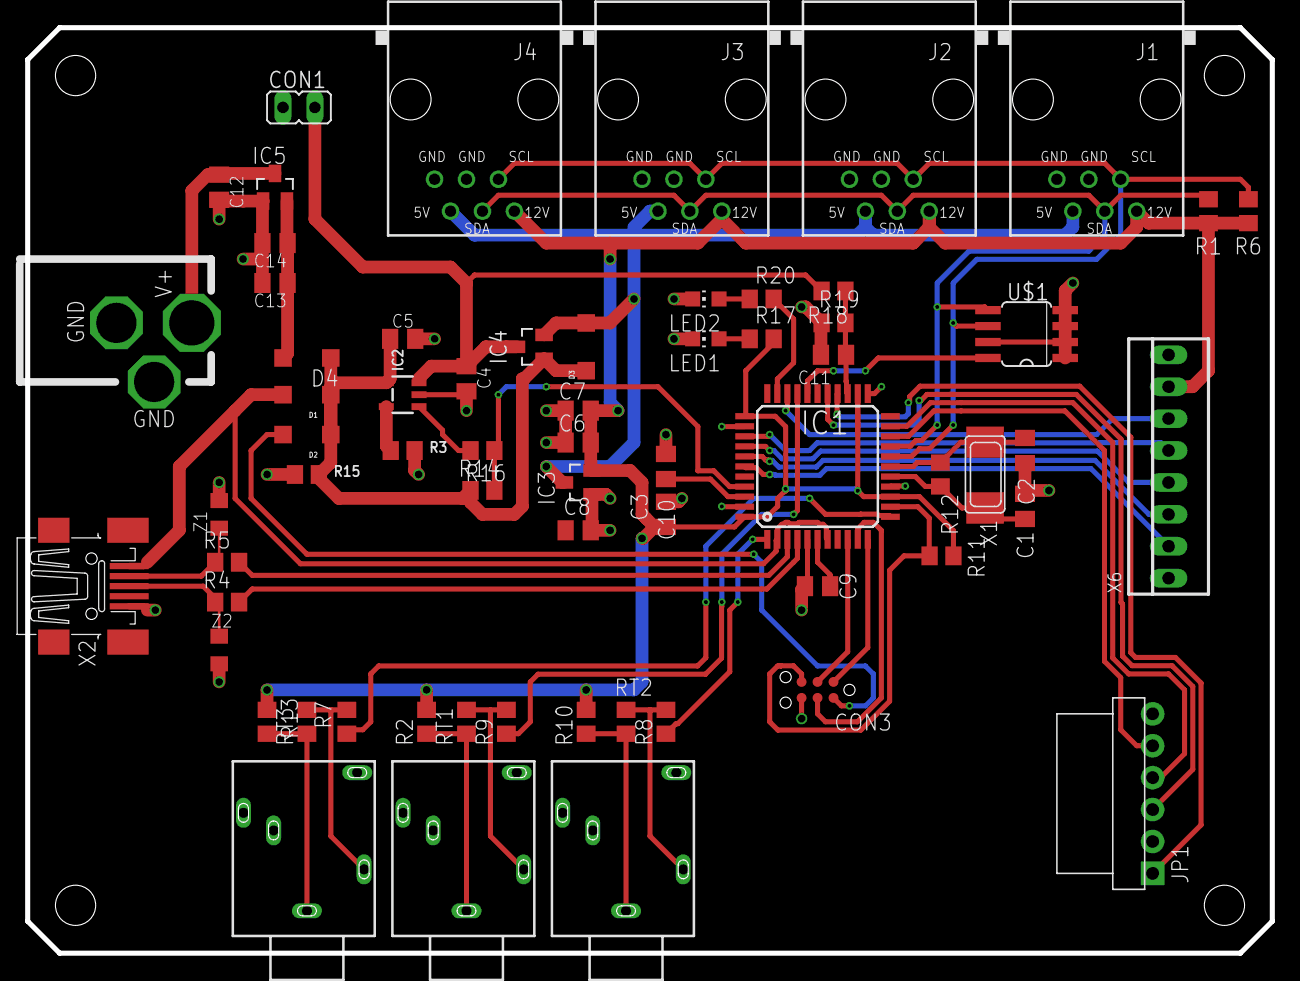
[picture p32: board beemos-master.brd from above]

Board: 2 copper layers, 99.1 x 73.7 mm, 65 parts (0 on the bottom side), 49 nets.

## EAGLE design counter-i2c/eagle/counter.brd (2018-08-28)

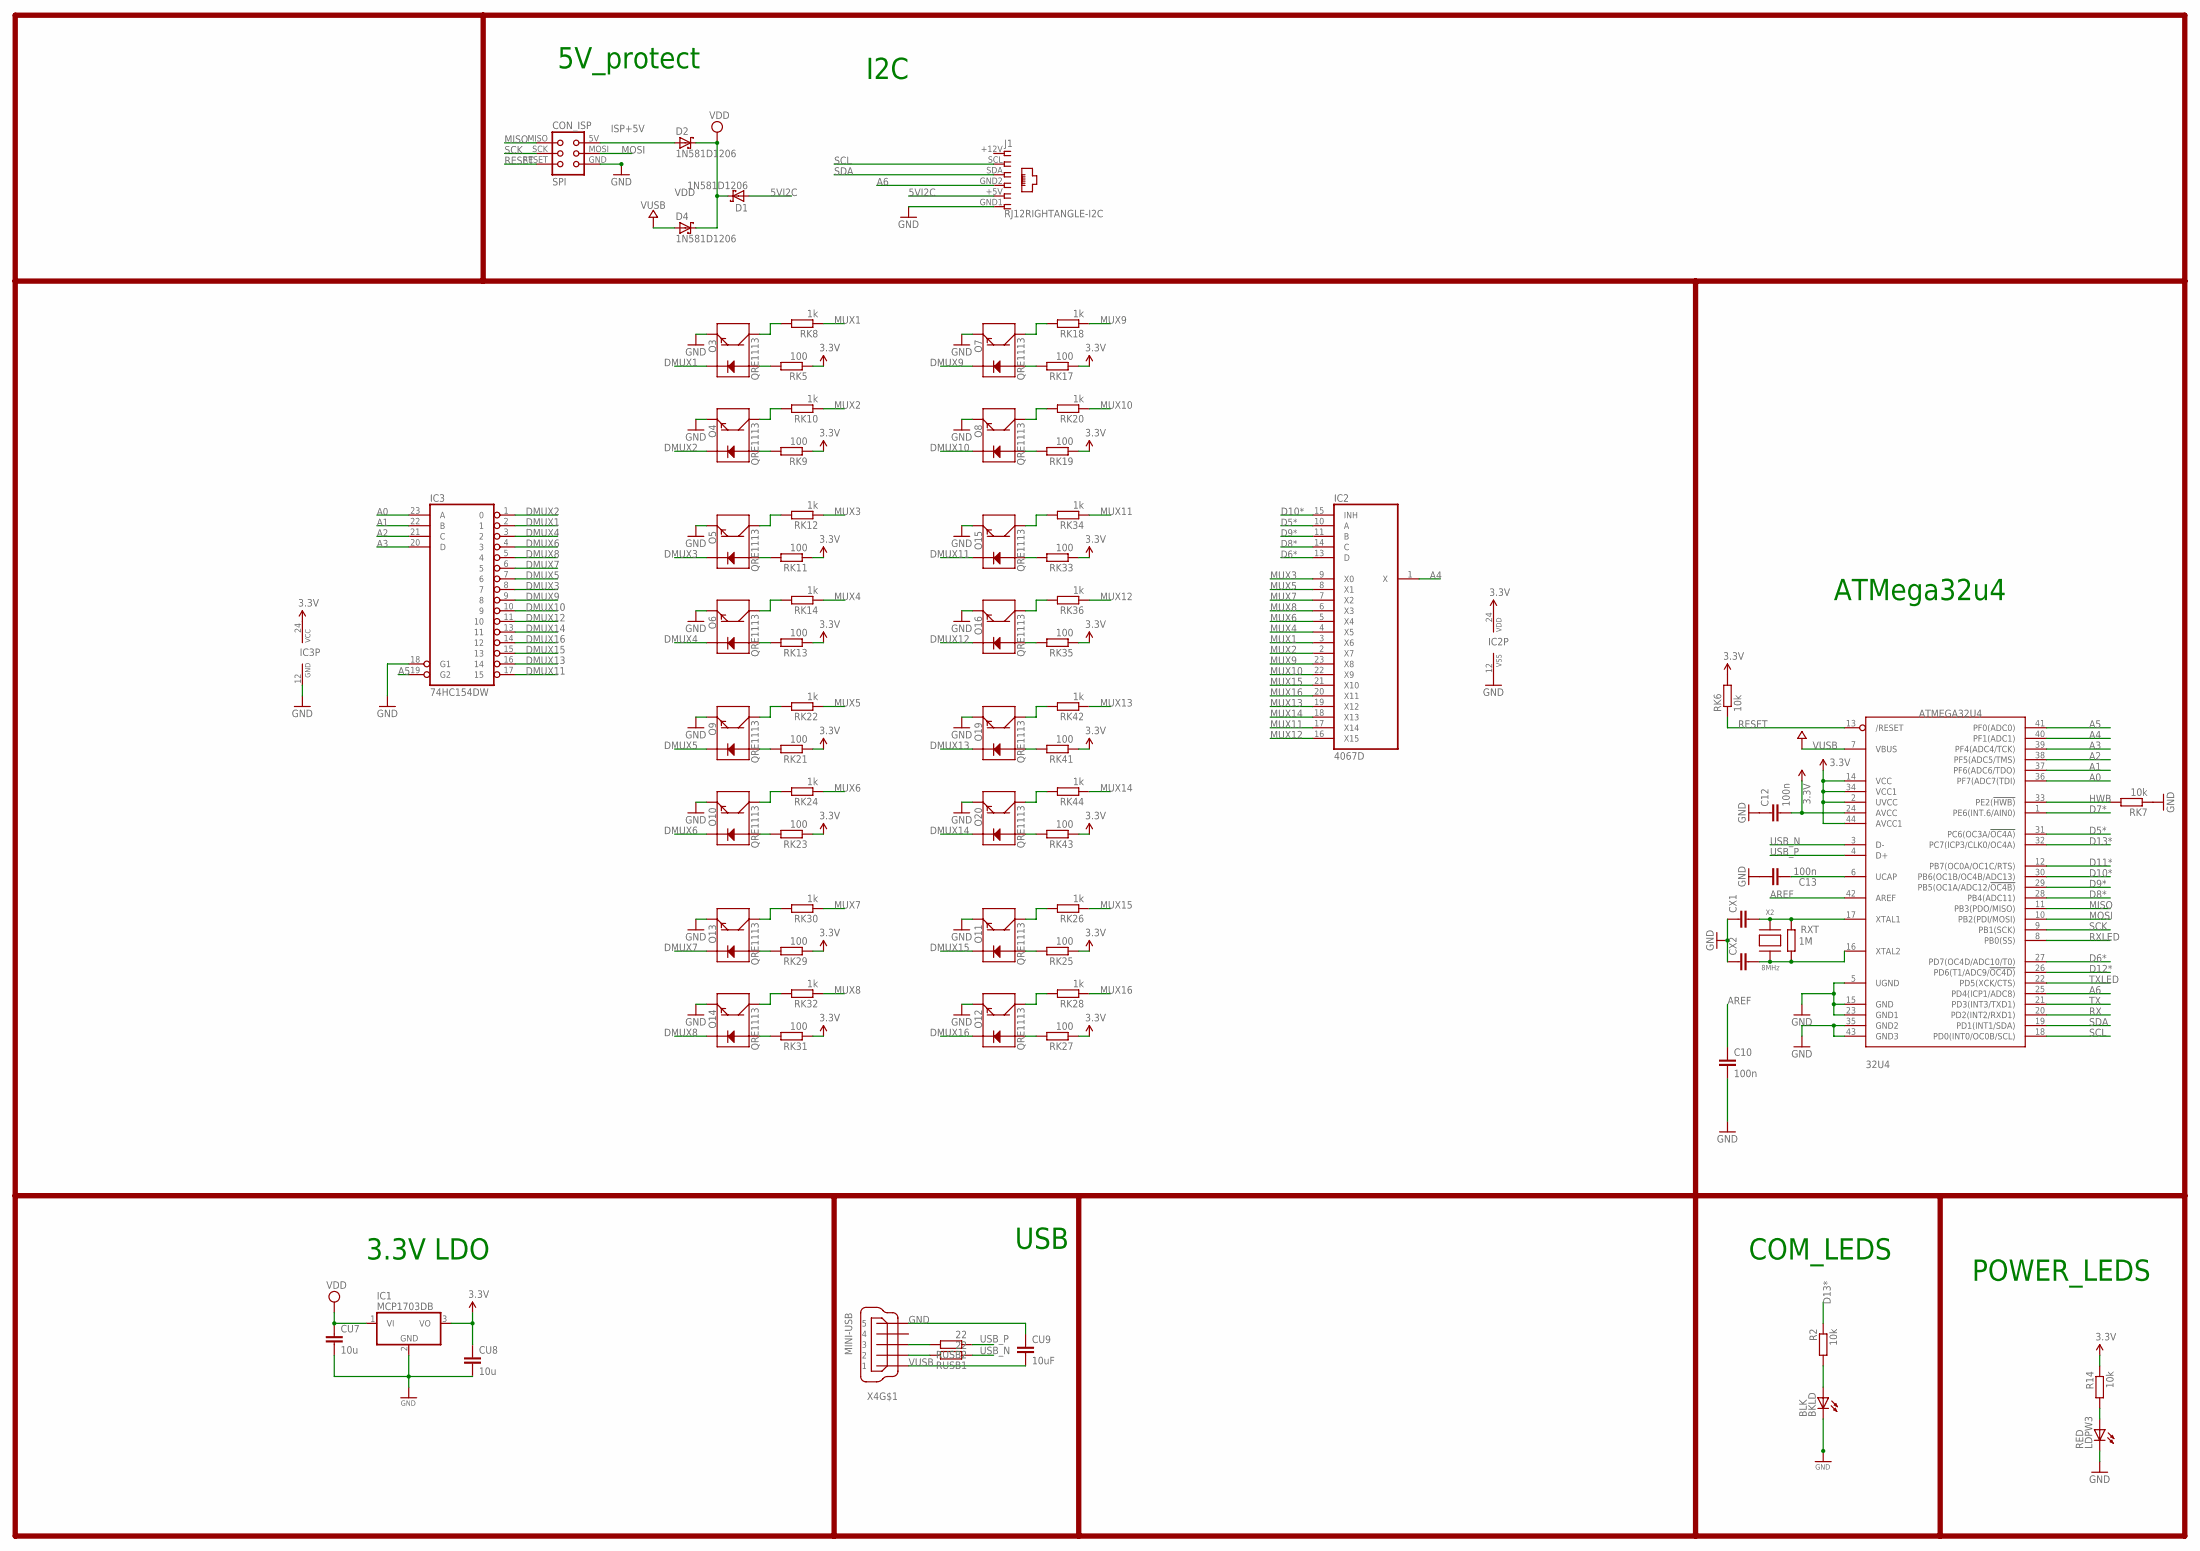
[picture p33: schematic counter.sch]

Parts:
32U4: ATMEGA32U4; TQFP44
BKLD: BLK; CHIP-LED0805
C10, C12, C13: 100n; C0805
CON_ISP: SPI; TC2030-MCP-NL
CU7, CU8: 10u; C0805
CU9: 10uF; C0805
CX1, CX2: 22pF; C0805
D1, D2, D4: 1N581D1206; LED-1206
IC1: MCP1703DB; SOT223
IC2: 4067D; SO24W
IC3: 74HC154DW; SO24W
J1: RJ12RIGHTANGLE-I2C; RJ12-RIGHTANGLE-I2C
LDPW3: RED; CHIP-LED0805
O3, O4, O5, O6, O7, O8, O9, O10, O11, O12, O13, O14, O15, O16, O19, O20: QRE1113
R2, R14: 10k; R0805
RK5, RK9, RK11, RK13, RK17, RK19, RK21, RK23, RK25, RK27, RK29, RK31, RK33, RK35, RK41, RK43: 100; M0805
RK6, RK7: 10k; M0805
RK8, RK10, RK12, RK14, RK18, RK20, RK22, RK24, RK26, RK28, RK30, RK32, RK34, RK36, RK42, RK44: 1k; M0805
RUSB1, RUSB2: 22; M0805
RXT: 1M; R0805
X2: 8MHz; NX6035
X4: MINI-USB; 32005-201

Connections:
1: J1.+12V (1)
3.3V: 32U4.2 (UVCC), 32U4.14 (VCC), 32U4.24 (AVCC), 32U4.34 (VCC1), 32U4.44 (AVCC1), C12.2, CU8.1, IC1.3 (VO), IC2.24 (VDD), IC3.24 (VCC), R14.1, RK5.1, RK6.2, RK9.1, RK11.1, RK13.1, RK17.1, RK19.1, RK21.1, RK23.1, RK25.1, RK27.1, RK29.1, RK31.1, RK33.1, RK35.1, RK41.1, RK43.1
5VI2C: D1.A, J1.+5V (5)
A0: 32U4.36 (PF7(ADC7(TDI)), IC3.23 (A)
A1: 32U4.37 (PF6(ADC6/TDO)), IC3.22 (B)
A2: 32U4.38 (PF5(ADC5/TMS)), IC3.21 (C)
A3: 32U4.39 (PF4(ADC4/TCK)), IC3.20 (D)
A4: 32U4.40 (PF1(ADC1)), IC2.1 (X)
A5: 32U4.41 (PF0(ADC0)), IC3.19 (G2)
A6: 32U4.25 (PD4(ICP1/ADC8)), J1.GND2 (4)
AREF: 32U4.42 (AREF), C10.1
D5*: 32U4.31 (PC6(OC3A/!OC4A)), IC2.10 (A)
D6*: 32U4.27 (PD7(OC4D/ADC10/T0)), IC2.13 (D)
D7*: 32U4.1 (PE6(INT.6/AIN0))
D8*: 32U4.28 (PB4(ADC11)), IC2.14 (C)
D9*: 32U4.29 (PB5(OC1A/ADC12/!OC4B)), IC2.11 (B)
D10*: 32U4.30 (PB6(OC1B/OC4B/ADC13)), IC2.15 (INH)
D11*: 32U4.12 (PB7(OC0A/OC1C/RTS))
D12*: 32U4.26 (PD6(T1/ADC9/!OC4D))
D13*: 32U4.32 (PC7(ICP3/CLK0/OC4A)), R2.1
DMUX1: IC3.2 (1), O3.2 (K)
DMUX2: IC3.1 (0), O4.2 (K)
DMUX3: IC3.8 (7), O5.2 (K)
DMUX4: IC3.3 (2), O6.2 (K)
DMUX5: IC3.7 (6), O9.2 (K)
DMUX6: IC3.4 (3), O10.2 (K)
DMUX7: IC3.6 (5), O13.2 (K)
DMUX8: IC3.5 (4), O14.2 (K)
DMUX9: IC3.9 (8), O7.2 (K)
DMUX10: IC3.10 (9), O8.2 (K)
DMUX11: IC3.17 (15), O15.2 (K)
DMUX12: IC3.11 (10), O16.2 (K)
DMUX13: IC3.16 (14), O19.2 (K)
DMUX14: IC3.13 (11), O20.2 (K)
DMUX15: IC3.15 (13), O11.2 (K)
DMUX16: IC3.14 (12), O12.2 (K)
GND: 32U4.5 (UGND), 32U4.15 (GND), 32U4.23 (GND1), 32U4.35 (GND2), 32U4.43 (GND3), BKLD.C, C10.2, C12.1, C13.1, CON_ISP.GND, CU7.2, CU8.2, CU9.1, CX1.1, CX2.1, IC1.2 (GND), IC2.12 (VSS), IC3.12 (GND), IC3.18 (G1), J1.GND1 (6), LDPW3.C, O3.4 (E), O4.4 (E), O5.4 (E), O6.4 (E), O7.4 (E), O8.4 (E), O9.4 (E), O10.4 (E), O11.4 (E), O12.4 (E), O13.4 (E), O14.4 (E), O15.4 (E), O16.4 (E), O19.4 (E), O20.4 (E), RK7.1, X4.5
HWB: 32U4.33 (PE2(!HWB)), RK7.2
ISP+5V: CON_ISP.5V (VCC), D2.A
MISO: 32U4.11 (PB3(PDO/MISO)), CON_ISP.MISO
MOSI: 32U4.10 (PB2(PDI/MOSI)), CON_ISP.MOSI
MUX1: IC2.3 (X6), RK8.1
MUX2: IC2.2 (X7), RK10.1
MUX3: IC2.9 (X0), RK12.1
MUX4: IC2.4 (X5), RK14.1
MUX5: IC2.8 (X1), RK22.1
MUX6: IC2.5 (X4), RK24.1
MUX7: IC2.7 (X2), RK30.1
MUX8: IC2.6 (X3), RK32.1
MUX9: IC2.23 (X8), RK18.1
MUX10: IC2.22 (X9), RK20.1
MUX11: IC2.17 (X14), RK34.1
MUX12: IC2.16 (X15), RK36.1
MUX13: IC2.19 (X12), RK42.1
MUX14: IC2.18 (X13), RK44.1
MUX15: IC2.21 (X10), RK26.1
MUX16: IC2.20 (X11), RK28.1
unnamed: 32U4.6 (UCAP), C13.2
unnamed: BKLD.A, R2.2
unnamed: LDPW3.A, R14.2
unnamed: 32U4.17 (XTAL1), CX1.2, RXT.2, X2.P$2
RD3: O3.1 (A), RK5.2
RD4: O4.1 (A), RK9.2
RD5: O5.1 (A), RK11.2
RD6: O6.1 (A), RK13.2
RD7: O7.1 (A), RK17.2
RD8: O8.1 (A), RK19.2
RD9: O9.1 (A), RK21.2
RD10: O10.1 (A), RK23.2
RD11: O11.1 (A), RK25.2
RD12: O12.1 (A), RK27.2
RD13: O13.1 (A), RK29.2
RD14: O14.1 (A), RK31.2
RD15: O15.1 (A), RK33.2
RD16: O16.1 (A), RK35.2
RD19: O19.1 (A), RK41.2
RD20: O20.1 (A), RK43.2
RESET: 32U4.13 (/RESET), CON_ISP.RESET, RK6.1
RX: 32U4.20 (PD2(INT2/RXD1))
RXLED: 32U4.8 (PB0(SS))
SCK: 32U4.9 (PB1(SCK)), CON_ISP.SCK
SCL: 32U4.18 (PD0(INT0/OC0B/SCL)), J1.SCL (2)
SDA: 32U4.19 (PD1(INT1/SDA)), J1.SDA (3)
TX: 32U4.21 (PD3(INT3/TXD1))
TXLED: 32U4.22 (PD5(XCK/CTS))
USBC_N: RUSB1.2, X4.2
USBC_P: RUSB2.2, X4.3
USB_N: 32U4.3 (D-), RUSB1.1
USB_P: 32U4.4 (D+), RUSB2.1
VDD: CU7.1, D1.C, D2.C, D4.C, IC1.1 (VI)
VUSB: 32U4.7 (VBUS), CU9.2, D4.A, X4.1
XTAL1: 32U4.16 (XTAL2), CX2.2, RXT.1, X2.P$1
Y3: O3.3 (C), RK8.2
Y4: O4.3 (C), RK10.2
Y5: O5.3 (C), RK12.2
Y6: O6.3 (C), RK14.2
Y7: O7.3 (C), RK18.2
Y8: O8.3 (C), RK20.2
Y9: O9.3 (C), RK22.2
Y10: O10.3 (C), RK24.2
Y11: O11.3 (C), RK26.2
Y12: O12.3 (C), RK28.2
Y13: O13.3 (C), RK30.2
Y14: O14.3 (C), RK32.2
Y15: O15.3 (C), RK34.2
Y16: O16.3 (C), RK36.2
Y19: O19.3 (C), RK42.2
Y20: O20.3 (C), RK44.2

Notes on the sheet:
USB
I2C
5V_protect
POWER_LEDS
COM_LEDS
3.3V LDO
ATMega32u4

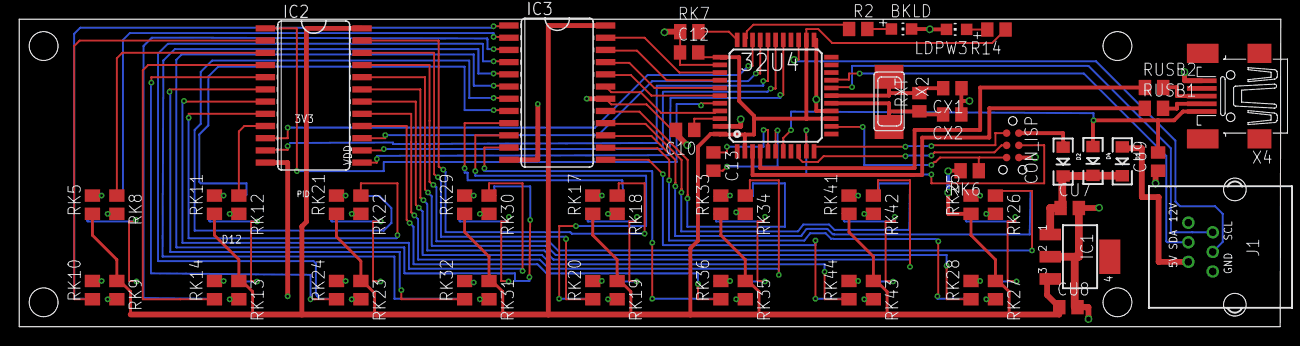
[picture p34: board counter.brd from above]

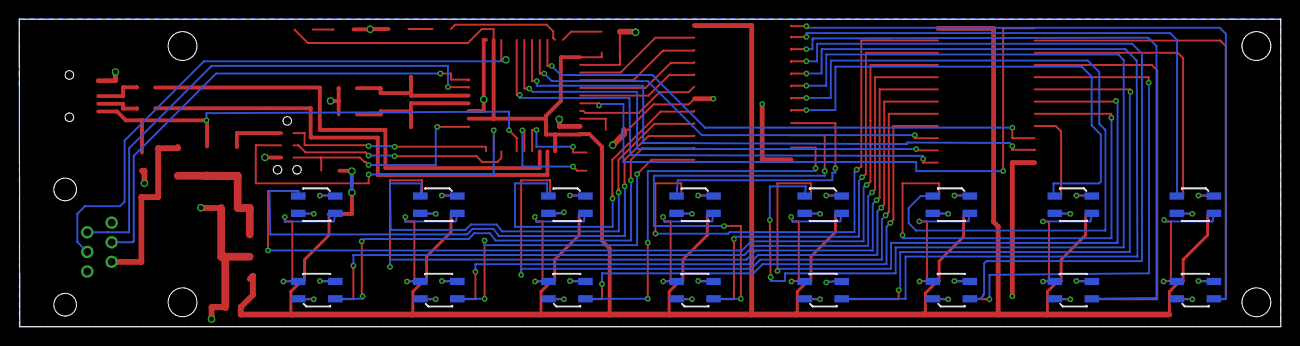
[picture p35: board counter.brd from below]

Board: 4 copper layers, 131.3 x 32.0 mm, 76 parts (16 on the bottom side), 100 nets.

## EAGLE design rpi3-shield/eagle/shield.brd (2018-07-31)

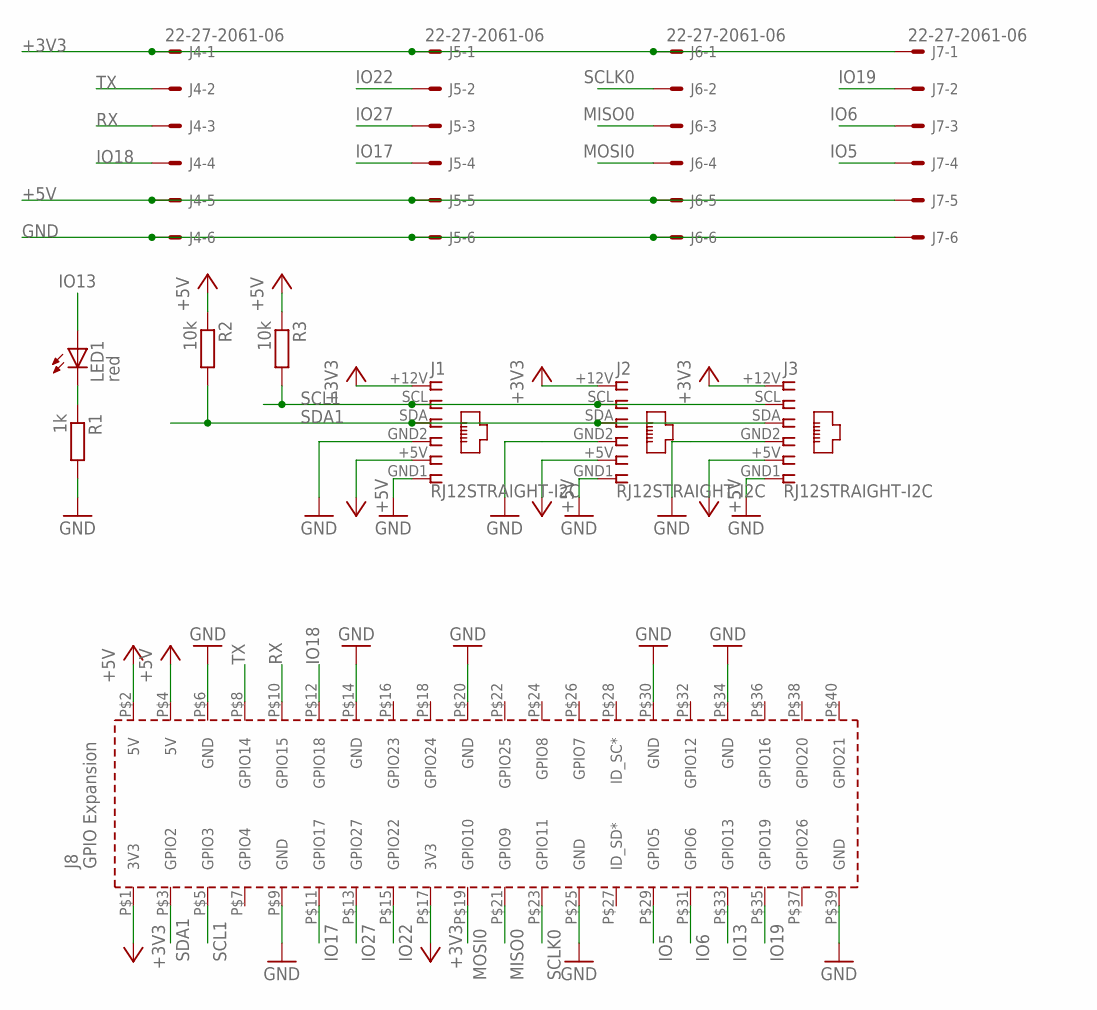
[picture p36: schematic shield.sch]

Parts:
J1, J2, J3: RJ12STRAIGHT-I2C; RJ12-STRAIGHT-I2C
J4, J5, J6, J7: 22-27-2061-06; 6410-06
LED1: red; SML0805
PCB1: RPI3RPI3MIRROR; RPI3MIRROR
R1: 1k; R0805
R2, R3: 10k; R0805

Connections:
+3V3: J1.+12V (1), J2.+12V (1), J3.+12V (1), J4.1, J5.1, J6.1, J7.1, PCB1.P$1 (3V3), PCB1.P$17 (3V3)
+5V: J1.+5V (5), J2.+5V (5), J3.+5V (5), J4.5, J5.5, J6.5, J7.5, PCB1.P$2 (5V), PCB1.P$4 (5V), R2.1, R3.1
GND: J1.GND1 (6), J1.GND2 (4), J2.GND1 (6), J2.GND2 (4), J3.GND1 (6), J3.GND2 (4), J4.6, J5.6, J6.6, J7.6, PCB1.P$6 (GND), PCB1.P$9 (GND), PCB1.P$14 (GND), PCB1.P$20 (GND), PCB1.P$25 (GND), PCB1.P$30 (GND), PCB1.P$34 (GND), PCB1.P$39 (GND), R1.2
IO5: J7.4, PCB1.P$29 (GPIO5)
IO6: J7.3, PCB1.P$31 (GPIO6)
IO13: LED1.A, PCB1.P$33 (GPIO13)
IO17: J5.4, PCB1.P$11 (GPIO17)
IO18: J4.4, PCB1.P$12 (GPIO18)
IO19: J7.2, PCB1.P$35 (GPIO19)
IO22: J5.2, PCB1.P$15 (GPIO22)
IO27: J5.3, PCB1.P$13 (GPIO27)
MISO0: J6.3, PCB1.P$21 (GPIO9)
MOSI0: J6.4, PCB1.P$19 (GPIO10)
unnamed: LED1.C, R1.1
RX: J4.3, PCB1.P$10 (GPIO15)
SCL1: J1.SCL (2), J2.SCL (2), J3.SCL (2), PCB1.P$5 (GPIO3), R3.2
SCLK0: J6.2, PCB1.P$23 (GPIO11)
SDA1: J1.SDA (3), J2.SDA (3), J3.SDA (3), PCB1.P$3 (GPIO2), R2.2
TX: J4.2, PCB1.P$8 (GPIO14)

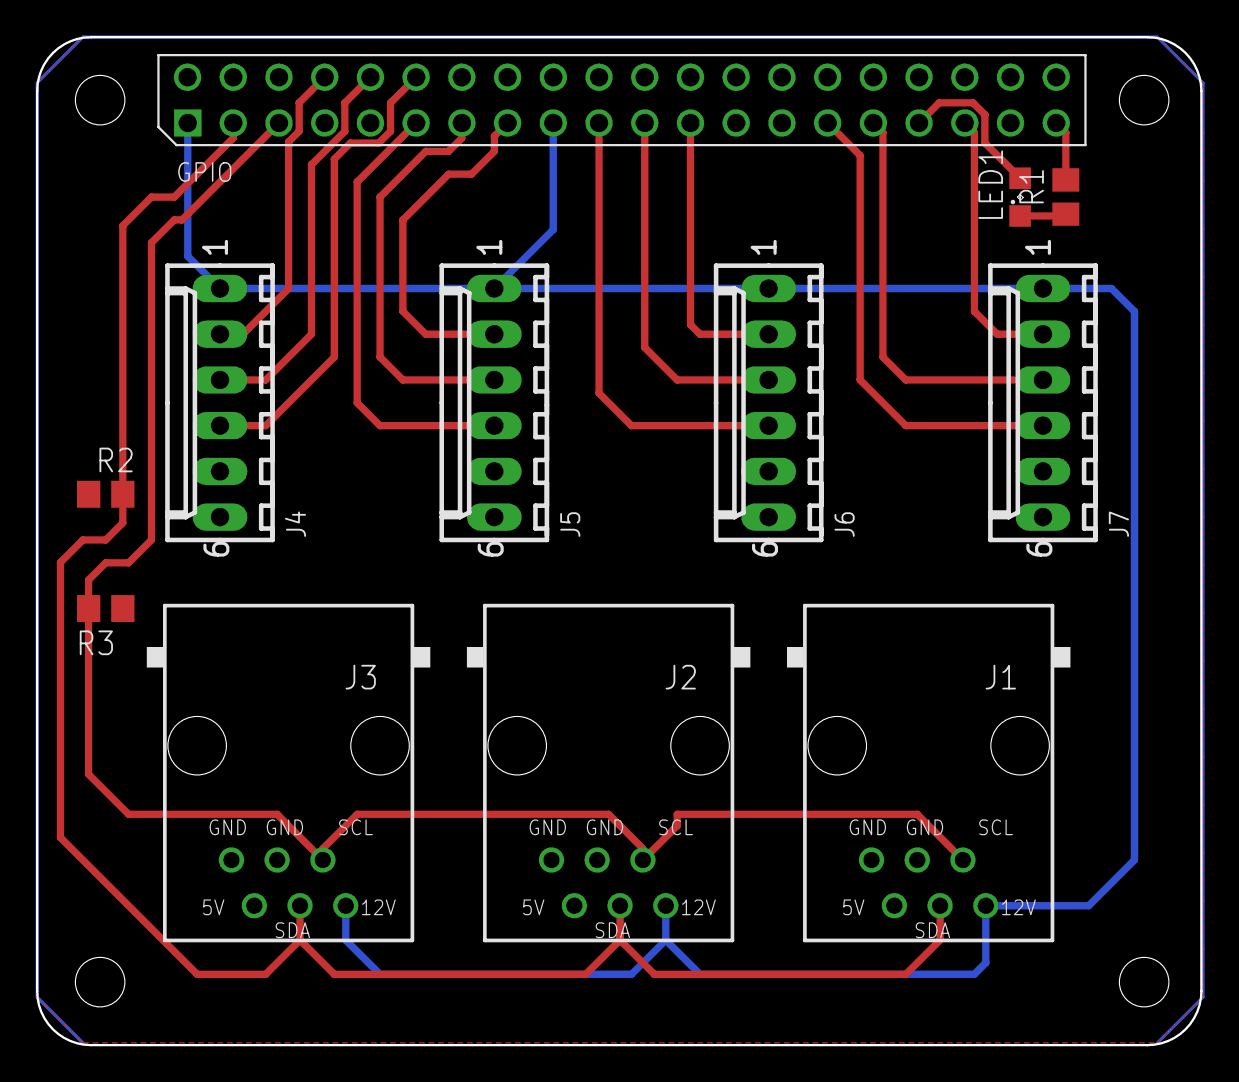
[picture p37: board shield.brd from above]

Board: 2 copper layers, 64.7 x 56.0 mm, 12 parts (1 on the bottom side), 19 nets.

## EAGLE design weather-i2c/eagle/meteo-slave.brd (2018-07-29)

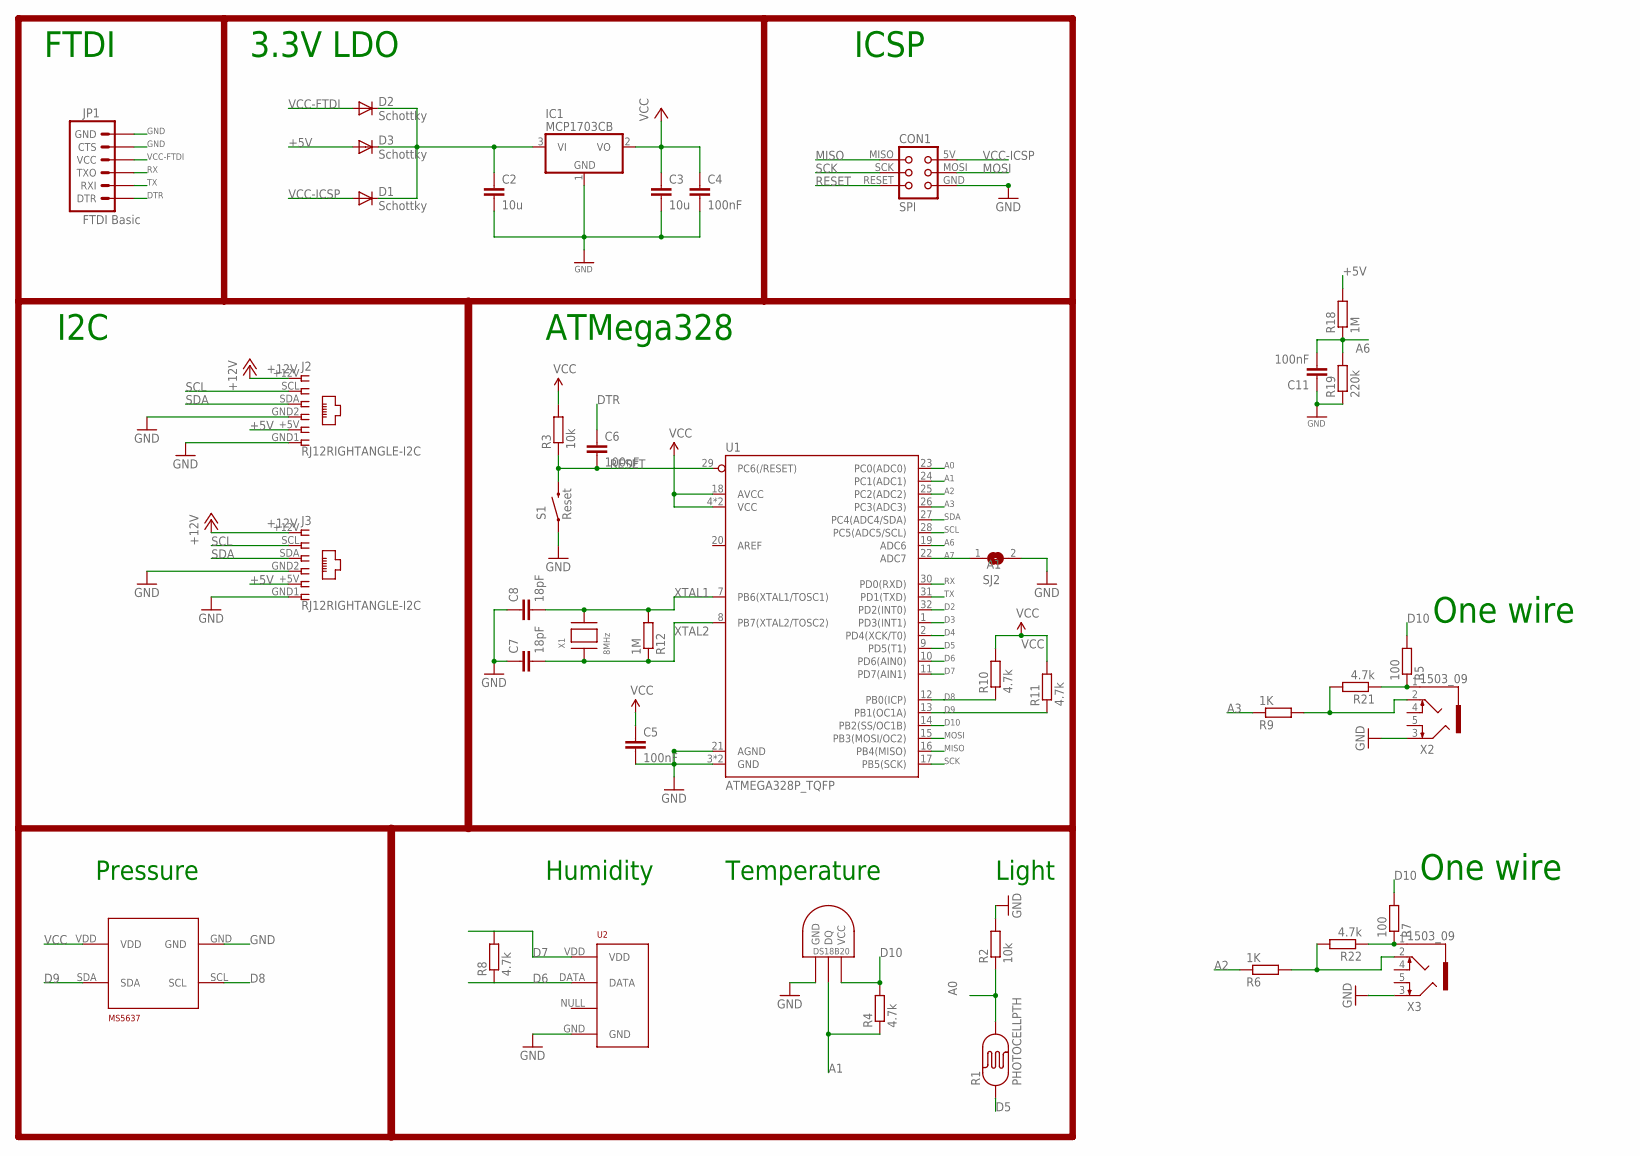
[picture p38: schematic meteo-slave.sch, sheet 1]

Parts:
C2, C3: 10u; C0805K; MPN 77-VJ1206V106ZXQTBC; LCSC C15850
C4, C5, C6, C11: 100nF; C0805K; MPN 80-C1206C104K5R; LCSC C49678
C7, C8: 18pF; C0805K; MPN 77-VJ1206A180JXXPBC; LCSC C1797
CON1: SPI; TC2030-MCP
D1, D2, D3: Schottky; SOD123; MPN 621-1N5819HW-F; LCSC C82544
IC1: MCP1703CB; SOT23; LCSC C53352
J2, J3: RJ12RIGHTANGLE-I2C; RJ12-RIGHTANGLE-I2C
JP1: FTDI Basic; 1X06
R1: PHOTOCELLPTH; PHOTOCELL
R2: 10k; R0805
R3: 10k; R0805; LCSC C17513
R4, R8, R10, R11, R21, R22: 4.7k; R0805
R5, R7: 100; R0805
R6, R9: 1K; R0805
R12, R18: 1M; R0805; LCSC C17514
R19: 220k; R0805; LCSC C17514
S1: Reset; TACTILE-SWITCH-SMD-ALT01
SJ2: A1; SJ
U1: ATMEGA328P_TQFP; TQFP32-08
U2: RHT03_DHT-22_AM2302; RHT03_DHT-22
U$1: DS1820TO92; DS1820
U$19: MS5637WIDE
X1: 8MHz; NX6035; MPN 729-F60800010; LCSC C122522
X2, X3: 1503_09

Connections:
+5V: D3.A, J2.+5V (5), J3.+5V (5), R18.2
+12V: J2.+12V (1), J3.+12V (1)
+XV: C2.1, D1.C, D2.C, D3.C, IC1.3 (VI)
A0: R1.2, R2.1, U1.23 (PC0(ADC0))
A1: R4.1, U1.24 (PC1(ADC1)), U$1.DQ
A2: R6.1, U1.25 (PC2(ADC2))
A3: R9.1, U1.26 (PC3(ADC3))
A6: C11.2, R18.1, R19.2, U1.19 (ADC6)
A7: SJ2.1, U1.22 (ADC7)
D2: U1.32 (PD2(INT0))
D3: U1.1 (PD3(INT1))
D4: U1.2 (PD4(XCK/T0))
D5: R1.1, U1.9 (PD5(T1))
D6: R8.1, U1.10 (PD6(AIN0)), U2.DATA
D7: R8.2, U1.11 (PD7(AIN1)), U2.VDD
D8: R10.1, U1.12 (PB0(ICP)), U$19.SCL
D9: R11.1, U1.13 (PB1(OC1A)), U$19.SDA
D10: R4.2, R5.2, R7.2, U1.14 (PB2(SS/OC1B)), U$1.VDD (VCC)
DTR: C6.1, JP1.1 (DTR)
GND: C2.2, C3.2, C4.2, C5.2, C7.1, C8.1, C11.1, CON1.GND, IC1.1 (GND), J2.GND1 (6), J2.GND2 (4), J3.GND1 (6), J3.GND2 (4), JP1.5 (CTS), JP1.6 (GND), R2.2, R19.1, S1.1, S1.2 (1), SJ2.2, U1.3 (GND), U1.5 (GND), U1.21 (AGND), U2.GND, U$1.GND, U$19.GND, X2.3, X3.3
MISO: CON1.MISO, U1.16 (PB4(MISO))
MOSI: CON1.MOSI, U1.15 (PB3(MOSI/OC2))
unnamed: R6.2, R22.2, X3.2
unnamed: R7.1, R22.1, X3.1
unnamed: R5.1, R21.1, X2.1
unnamed: R9.2, R21.2, X2.2
RESET: C6.2, CON1.RESET, R3.1, S1.3 (2), S1.4 (2), U1.29 (PC6(/RESET))
RX: JP1.3 (TXO), U1.30 (PD0(RXD))
SCK: CON1.SCK, U1.17 (PB5(SCK))
SCL: J2.SCL (2), J3.SCL (2), U1.28 (PC5(ADC5/SCL))
SDA: J2.SDA (3), J3.SDA (3), U1.27 (PC4(ADC4/SDA))
TX: JP1.2 (RXI), U1.31 (PD1(TXD))
VCC: C3.1, C4.1, C5.1, IC1.2 (VO), R3.2, R10.2, R11.2, U1.4 (VCC), U1.6 (VCC), U1.18 (AVCC), U$19.VDD
VCC-FTDI: D2.A, JP1.4 (VCC)
VCC-ICSP: CON1.5V (VCC), D1.A
XTAL1: C8.2, R12.2, U1.7 (PB6(XTAL1/TOSC1)), X1.P$2
XTAL2: C7.2, R12.1, U1.8 (PB7(XTAL2/TOSC2)), X1.P$1

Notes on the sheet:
ICSP
ATMega328
3.3V LDO
I2C
FTDI
Light
Temperature
Humidity
Pressure
One wire

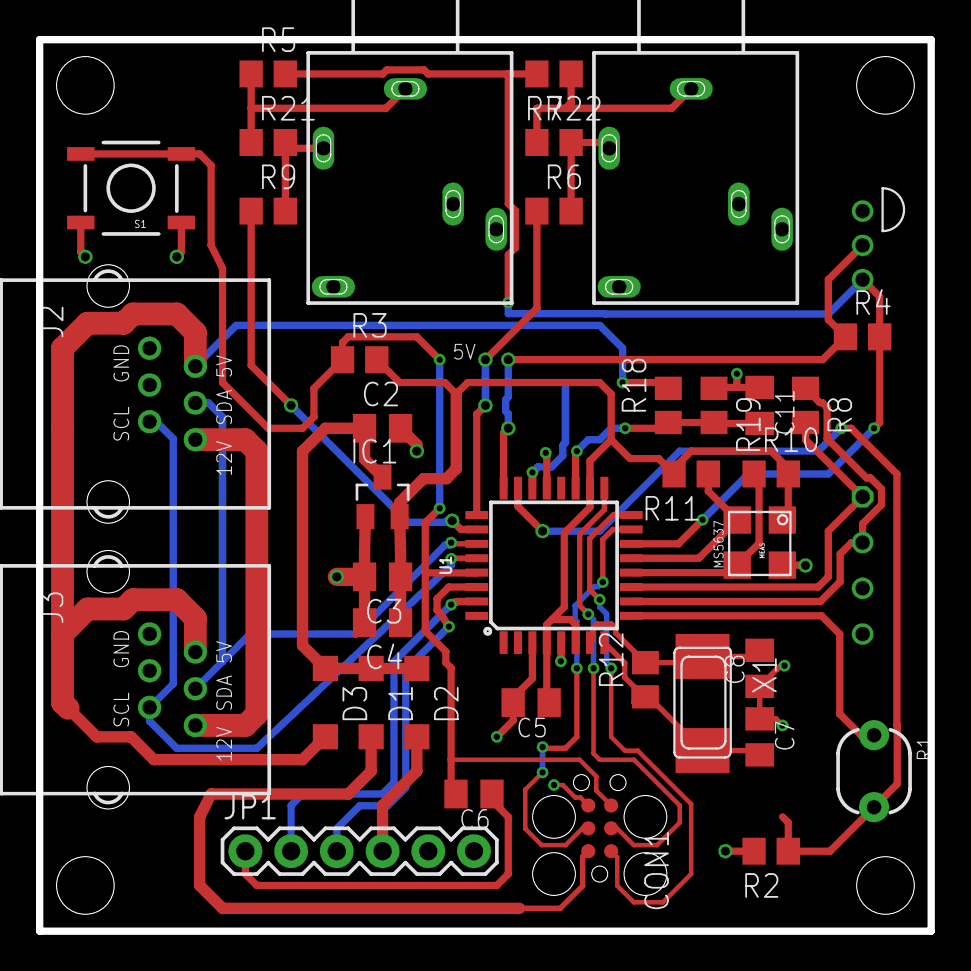
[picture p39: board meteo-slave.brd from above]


Board: 2 copper layers, 49.5 x 49.5 mm, 41 parts (2 on the bottom side), 34 nets.

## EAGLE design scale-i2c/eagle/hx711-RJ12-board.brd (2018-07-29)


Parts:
8.2K: 8.2k; M0805
20K: 20k; M0805
BJ1: MMBT4403; SOT23-3
C12, C13, C14, C15: 100n; C0805
CU1, CU2: 10u; C0805
J8: RJ123.3; RJ12-STRAIGHT-3.3
RK5: 10k; M0805
RL1, RL2: 100; M0805
SJ2: JUMPER-PAD-2-NC_BY_TRACE; PAD-JUMPER-2-NC_BY_TRACE_YES_SILK
SJ3: SJ
U1: HX711; SO16
WGT: M05PTH; 1X05

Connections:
3.3V: BJ1.2 (E), C12.1, CU1.1, RK5.2, U1.1 (VSUP), U1.16 (DVDD)
A4: U1.12 (DOUT)
A5: U1.11 (PD_SCK)
A+: RL2.2, WGT.2
A-: RL1.2, WGT.3
CN3: C14.2, U1.6 (VBG)
GND: C12.2, CU1.2, SJ2.1, SJ3.2, U1.14 (XI), WGT.1, WGT.4
LGND: 8.2K.1, C13.2, C14.1, CU2.2, SJ2.2, U1.5 (AGND)
unnamed: 20K.2, BJ1.3 (C), C13.1, CU2.1, U1.3 (AVDD), WGT.5
unnamed: C15.2, RL1.1, U1.7 (INA-)
unnamed: BJ1.1 (B), U1.2 (BASE)
unnamed: 8.2K.2, 20K.1, U1.4 (VFB)
unnamed: RK5.1, SJ3.1, U1.15 (RATE)
unnamed: C15.1, RL2.1, U1.8 (INA+)

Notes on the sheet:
VCC: 2.7-5.5V
VBG = 1.25V
AVDD = VBG(R1+R2)/R1
Default: Closed - Data rate set to 10SPS
Open jumper to set to 80SPS Increases noise per read
Red
Black
White
IO: 2.7-5.5V
Shield
Yellow
Load cell 24bits ADC


Board: 2 copper layers, 44.5 x 27.9 mm, 17 parts (0 on the bottom side), 12 nets.

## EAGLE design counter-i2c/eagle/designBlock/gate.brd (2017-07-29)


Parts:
C1, C3: 10n; C0805
O1, O2: QRE1113
RK1, RK3: 1k; M0805
RK2, RK4: 220; M0805

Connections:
3.3V: C1.2, C3.2, RK1.1, RK3.1
DMUX1: O1.2 (K)
DMUX2: O2.2 (K)
GND: O1.4 (E), O2.4 (E)
MUX1: RK4.1
MUX2: RK2.1
RD1: O1.1 (A), RK3.2
RD2: O2.1 (A), RK1.2
Y1: C3.1, O1.3 (C), RK4.2
Y2: C1.1, O2.3 (C), RK2.2



Board: 2 copper layers, 8 parts (2 on the bottom side), 6 nets.

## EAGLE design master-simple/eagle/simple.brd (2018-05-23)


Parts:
5V-OK1: RED; CHIP-LED0805
C2, C8: 22pF; C0805K
C3, C11: 100nF; C0805K
C5, C6: 10u; C0805K; MPN 77-VJ1206V106ZXQTBC; LCSC C15850
C7: 100nF; C0805K; MPN 80-C1206C104K5R; LCSC C49678
CON3: SPI; TC2030-MCP-NL
D1, D2, D3, D6: Schottky; SOD123; MPN 621-1N5819HW-F; LCSC C82544
F1: 1.2A; C1812
F3: 0.5A; C1812
IC1: MCP1703CB; SOT23; LCSC C53352
J1, J2, J3: RJ12RIGHTANGLE-I2C; RJ12-RIGHTANGLE-I2C
L13: BLUE; CHIP-LED0805
LED10: GREEN; CHIP-LED0805
R1, R15: 10k; M0805
R2, R3, R6, R7, R8, R9: 100; R0805
R4, R5: 22; R0805; LCSC C17561
R10, R12: 4.7k; R0805
R11: 1K; R0805
R13: 1M; M0805
R31: 10K; R0805
R111: 10k; R0805
U$1: TSOP4838; PNA460XM
U$4: 32U4; TQFP44
U$6: KPJX-4S-S
UART: M05PTH; 1X05
X1: MINI-USB; 32005-201; MPN 649-10033526-N3212LF; LCSC C46391
X3: 8MHz; NX6035
Z1, Z2: VARISTOR; CT/CN0603

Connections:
+3V3: C6.1, C7.1, IC1.2 (VO), R10.1, R12.1, R15.2, R31.1, U$1.3 (VCC), U$4.2 (UVCC), U$4.14 (VCC), U$4.24 (AVCC), U$4.34 (VCC1), U$4.44 (AVCC1), UART.2
+5V: F3.2, J1.+5V (5), J2.+5V (5), J3.+5V (5), UART.1
+12V: F1.2, J1.+12V (1), J2.+12V (1), J3.+12V (1), R111.2
+XV: C5.1, D1.C, D3.C, IC1.3 (VI)
A0: U$4.36 (PF7(ADC7(TDI))
A1: U$4.37 (PF6(ADC6/TDO))
A2: U$4.38 (PF5(ADC5/TMS))
A3: U$4.39 (PF4(ADC4/TCK))
A4: U$4.40 (PF1(ADC1))
A5: U$4.41 (PF0(ADC0))
AREF: C11.1, U$4.42 (AREF)
CS: U$4.25 (PD4(ICP1/ADC8))
D5: U$4.31 (PC6(OC3A/!OC4A))
D6: U$4.27 (PD7(OC4D/ADC10/T0))
D7: R11.2, U$4.1 (PE6(INT.6/AIN0))
D8: U$4.28 (PB4(ADC11))
D9: U$4.29 (PB5(OC1A/ADC12/!OC4B))
D10: U$4.30 (PB6(OC1B/OC4B/ADC13))
D11: U$4.12 (PB7(OC0A/OC1C/RTS))
D12: U$4.26 (PD6(T1/ADC9/!OC4D))
D13: R1.2, U$4.32 (PC7(ICP3/CLK0/OC4A))
GND: 5V-OK1.C, C2.1, C3.1, C5.2, C6.2, C7.2, C8.1, C11.2, CON3.GND, IC1.1 (GND), J1.GND1 (6), J1.GND2 (4), J2.GND1 (6), J2.GND2 (4), J3.GND1 (6), J3.GND2 (4), L13.C, LED10.C, U$1.2 (GND), U$4.5 (UGND), U$4.15 (GND), U$4.23 (GND1), U$4.35 (GND2), U$4.43 (GND3), U$6.GND1, U$6.GND2, UART.5, X1.5, Z1.2, Z2.1
HWB: U$4.33 (PE2(!HWB))
MISO: CON3.MISO, U$4.11 (PB3(PDO/MISO))
MOSI: CON3.MOSI, U$4.10 (PB2(PDI/MOSI))
unnamed: J2.SCL (2), R6.1
unnamed: J1.SCL (2), R2.1
unnamed: J1.SDA (3), R3.1
unnamed: L13.A, R1.1
unnamed: D2.C, D3.A, D6.C, F3.1
unnamed: J2.SDA (3), R7.1
unnamed: J3.SCL (2), R8.1
unnamed: J3.SDA (3), R9.1
unnamed: R11.1, U$1.1 (OUT)
unnamed: 5V-OK1.A, R31.2
unnamed: C3.2, U$4.6 (UCAP)
unnamed: F1.1, U$6.+12V
unnamed: C8.2, R13.2, U$4.17 (XTAL1), X3.P$2
unnamed: LED10.A, R111.1
PWR-5V: D6.A, U$6.+5V
RD+: R4.1, U$4.4 (D+)
RD-: R5.1, U$4.3 (D-)
RESET: CON3.RESET, R15.1, U$4.13 (/RESET)
RX: U$4.20 (PD2(INT2/RXD1)), UART.4
RXLED: U$4.8 (PB0(SS))
SCK: CON3.SCK, U$4.9 (PB1(SCK))
SCL: R2.2, R6.2, R8.2, R10.2, U$4.18 (PD0(INT0/OC0B/SCL))
SDA: R3.2, R7.2, R9.2, R12.2, U$4.19 (PD1(INT1/SDA))
TX: U$4.21 (PD3(INT3/TXD1)), UART.3
TXLED: U$4.22 (PD5(XCK/CTS))
USBC_N: R5.2, X1.2, Z1.1
USBC_P: R4.2, X1.3, Z2.2
VCC-ICSP: CON3.5V (VCC), D1.A
VUSB: D2.A, U$4.7 (VBUS), X1.1
XTAL1: C2.2, R13.1, U$4.16 (XTAL2), X3.P$1

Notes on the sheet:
IR receiver
ICSP
Microcontroller
USB
3.3V LDO
Power supply
Serial extension
I2C extensions


Board: 2 copper layers, 75.0 x 43.0 mm, 45 parts (0 on the bottom side), 38 nets.

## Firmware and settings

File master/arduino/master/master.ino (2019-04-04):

// including libraries, defining main pins used and setting up general setup and loop.


#define MAX_PARAM 32

#define LOGGER_I2C_EEPROM  80  // I2C address of M24512 eeprom

#define SCALE_I2C_ADDRESS           16
#define WEATHER_I2C_ADDRESS         55
#define COUNTER_I2C_ADDRESS         59

#define THR_SERIAL    1

#define THR_WIRE_MASTER
// #define WIRE_MASTER_HOT_PLUG    1   // scan automatically the i2c port for new slaves and prevents SLEEP !!!

#define BATTERY               A6  // if battery we have also the temperature sensor
#define BATTERY_CHARGING      A5

#include "libino/hack.h"


void setup() {

  pinMode(9, OUTPUT); // turn on the memory
  digitalWrite(9, HIGH);

  start();
}

void loop() {}

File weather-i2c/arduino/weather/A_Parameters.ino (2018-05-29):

/*********************************************
   This file is used to declare the parameters
   table used by the program.

   We use the EEPROM for saving the parameters
   changed by the user during the functionment
   of the Bioreactor.

   The parameters are loaded during the boot.

   All important changes made on a parameter are saved
   in the EEPROM.
 *********************************************/


#define PARAM_LOGID               0
#define PARAM_SECONDS             1 // number of secodns since the last log
#define PARAM_TEMPERATURE_EXT     2
#define PARAM_TEMPERATURE_IN      3
#define PARAM_TEMPERATURE_BOARD   4
#define PARAM_HUMIDITY            5
#define PARAM_HUMIDITY_TEMP       6
#define PARAM_LUMINOSITY          7
#define PARAM_PRESSURE            8
#define PARAM_PRESSURE_TEMP       9

#define PARAM_LOGGING_INTERVAL    24    // minimal 300s to prevent desctruction of EEPROM. Should last 22 years with 300s
#define PARAM_SLEEP_DELAY         25

// you may write in EEPROM max 100'000 times
// 100'000 * 300 * 24 (number of line of log) / 365 / 86400


void resetParameters() { // turn all parameters to 0
  setAndSaveParameter(PARAM_SECONDS, 0);
  setAndSaveParameter(PARAM_LOGGING_INTERVAL, 3600);
  setAndSaveParameter(PARAM_SLEEP_DELAY, 10);

  setAndSaveParameter(PARAM_PRESSURE, PARAM_SLEEP_DELAY);
  setAndSaveParameter(PARAM_TEMPERATURE_EXT, ERROR_VALUE);
  setAndSaveParameter(PARAM_TEMPERATURE_IN, ERROR_VALUE);
  setAndSaveParameter(PARAM_TEMPERATURE_BOARD, ERROR_VALUE);
  setAndSaveParameter(PARAM_HUMIDITY, ERROR_VALUE);
  setAndSaveParameter(PARAM_HUMIDITY_TEMP, ERROR_VALUE);
  setAndSaveParameter(PARAM_LUMINOSITY, ERROR_VALUE);
  setAndSaveParameter(PARAM_PRESSURE, ERROR_VALUE);

#ifdef THR_LOGGER
  formatLog();
#endif
  setQualifier(ERROR_VALUE);
}

// This will be executed once on boot
void initParameters() {
  setParameter(PARAM_TEMPERATURE_EXT, ERROR_VALUE);
  setParameter(PARAM_TEMPERATURE_IN, ERROR_VALUE);
  setParameter(PARAM_TEMPERATURE_BOARD, ERROR_VALUE);
  setParameter(PARAM_HUMIDITY, ERROR_VALUE);
  setParameter(PARAM_HUMIDITY_TEMP, ERROR_VALUE);
  setParameter(PARAM_LUMINOSITY, ERROR_VALUE);
  setParameter(PARAM_PRESSURE, ERROR_VALUE);
}

void checkParameters() {
  if (getParameter(PARAM_LOGGING_INTERVAL) < 0) {
    resetParameters();
  }
}

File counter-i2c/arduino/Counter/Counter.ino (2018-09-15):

// including libraries, defining main pins used and setting up general setup and loop.

#define THR_WIRE_SLAVE 59         // specify the address of the i2c slave
#define WIRE_SLAVE_COMMAND    1   // we have some specific wire commands

// #define LOGGER 1

#define MAX_PARAM 52

#define THR_SERIAL    1

#include "libino/hack.h"

void setup() {
 start();
}

void loop() {}

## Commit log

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2017-05-30 Places 16 IR LED emitter/receptors on board layout with defined distances, other parts can me moved to layout board.
    [counter.brd, counter.sch]
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2017-07-26 set 74HC154D to gnd
    [counter.brd, counter.sch]
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2017-07-30 work in progress on slaveMeteo
    [slaveMeteo.brd, slaveMeteo.sch]
2017-08-14 first version of counter for production
    [counter.brd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]
2018-02-09 commented testOut and corrected mistake in binary values
    [testOut.ino]
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2018-03-13 Started FreeCAD project and designed PCB floor for the enclosure
    [beemos_enclosure.FCStd]
2018-03-20 designed side walls for the enclosure
    [beemos_enclosure.FCStd]
2018-03-27 finished designing beemos enclosure in freeCAD
    [beemos_enclosure.FCStd]
2018-04-07 corrected enclosure plancs to correctly change with thickness
    [beemos_enclosure.FCStd, beemos_enclosure.dxf]
2018-04-10 realigned opening for USB port and adapted other parts accordingly
    [beemos_enclosure.FCStd]
2018-04-19 reorganized directories and incorporated beemos-master into the repository
    [beemos-master.brd, beemos-master.sch, beemos_enclosure.FCStd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]
2018-04-20 updated eagle libraries and readme, started designing meteo station
    [slaveMeteo.brd, slaveMeteo.sch]
2018-04-21 working on i2c-slave basic board
    [slave-basic.brd, slave-basic.sch]
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2018-04-21 connected components on Slave meteo. Kept backup in case we still need a sound detector
    [slaveMeteo.brd, slaveMeteo.sch]
2018-04-21 reorganized components oon brd file for meteoslave
    [slaveMeteo.brd]
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2018-04-22 redesigned meteoSlave using slave-basic
    [slaveMeteo.brd, slaveMeteo.sch]
2018-04-22 moved all slaves to slave folder
    [counter.brd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]
2018-04-22 add documentation and move lcd-screen
    [slave-basic.brd, slave-basic.sch]
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2018-04-22 rename lcd-slave and add address selector
    [lcd-screen.brd, lcd-screen.sch, slaveMeteo.brd]
2018-04-22 standardised file and folder names for meteo-slave
    [meteo-slave.brd, meteo-slave.sch, slaveMeteo.brd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]
2018-04-22 add crystal to bard
    [lcd-screen.brd, lcd-screen.sch]
2018-04-22 working on a simple master
    [simple.brd, simple.sch]
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2018-04-23 finalize first version of master-simple
    [simple.brd, simple.sch]
2018-04-23 update cam processor to deal correcty with drill
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2018-04-24 Added LoRa and OneWire to schematics
    [beemos-master.brd, beemos-master.sch]
2018-05-01 work on weight slave
    [scale-slave.brd, scale-slave.sch]
2018-05-06 change resistor for led
    [counter.brd, counter.sch]
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2018-05-06 change resistor to 1k
    [counter.brd, counter.sch]
2018-05-06 add label on doors
    [counter.brd]
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2018-05-07 fix log to enable 27 logs every 1h
    [CounterThread.ino, Logger.ino, SerialSpecific.ino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]
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2018-05-08 added bee counter PCB soldering doc v1.0
    [beemos-master.brd, beemos-master.sch]
2018-05-08 increasing IR detector pad size
    [counter.brd, counter.sch, meteo-slave.brd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]
2018-05-09 Updated counter doc, new box design in FreeCAD (fixations for gates on main floor, bigger board compartment to include RJ12 socket, new hole for RJ12 socket and also below it to ensure board is flat 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
    [counterBox_v3.FCstd, counterBox_v3.dxf]
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2018-05-12 Added fixation for side walls, re-exported dxf file
    [counterBox_v3.FCstd, counterBox_v3.dxf]
2018-05-13 remove meteo capacitor for AREF
    [meteo-slave.brd, meteo-slave.sch]
2018-05-14 Modified holes from side wall for USB and RJ12, corrected location of fixations on ceiling, changed size of front/back wall cover
    [counterBox_v3_1.FCstd, counterBox_v3_1.dxf]
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2018-05-16 move address selector pad in meteo board
    [meteo-slave.brd]
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2018-05-17 meteo-slave: add voltage monitoring of i2c
    [meteo-slave.brd, meteo-slave.sch]
2018-05-17 meteo-slave: change light control to use internal pullup
    [meteo-slave.brd, meteo-slave.sch]
2018-05-19 move files for meteo-i2c
    [meteo-slave.brd, meteo-slave.sch]
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2018-05-19 revert to resistor for LDR to be able to tune
    [meteo-slave.brd, meteo-slave.sch]
2018-05-19 master-simple: add arduino code
    [simple.brd, simple.sch]
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2018-05-19 meteo-i2c: remove wrong test
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2018-05-20 master-simple: enable watch dog
    [counterBox_v3_1.FCstd, counterBox_v3_1.dxf]
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2018-05-20 counter-i2c: move openscad files
    [BeeMoS_box.scad]
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2018-05-22 Write one README for each board and refactor directories
    [beemos-master.brd, beemos-master.sch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]
2018-05-22 cleaned obsolete folders post refactor
    [beemos-master.brd, beemos-master.sch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]
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2018-05-28 weather-slave: add 4.7k for humidity sensor
    [meteo-slave.brd, meteo-slave.sch]
2018-05-28 weather-slave: add annotation for pressure sensor
    [meteo-slave.brd]
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2018-05-29 Almost finished beemos master board (labels to do still)
    [beemos-master.brd, beemos-master.sch]
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2018-06-08 Arranged labels and resistors in beemos master board layout
    [beemos-master.brd, beemos-master.sch]
2018-06-08 Fixed airwires/clearance for beemos master board
    [beemos-master.brd]
2018-06-09 Added power/com LEDs, extra pins exposed, cristal symmetric
    [beemos-master.brd, beemos-master.sch]
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2018-06-15 format detailed counter reame. move all eagle files for weather-i2c and update readme.
    [meteo-slave.brd, meteo-slave.sch]
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2018-07-24 initiate enclosure sketch for master and scale boards.
    [enclosure_scale_master.fcstd]
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2018-07-29 fix the +3.3V
    [scale-slave.brd, scale-slave.sch]
2018-07-29 correct resistor for voltage check
    [scale-slave.brd, scale-slave.sch]
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2018-07-29 weather-i2c: fix voltage check resistor value
    [meteo-slave.brd, meteo-slave.sch]
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2018-08-22 master: correct logger delay and writelog after format
    [LoggerM24512.ino]
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2018-08-25 Replace image load cell wiring
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2018-08-26 scale: add resetCounter, BA command from I2C
    [A_Parameters.ino, Counter.ino, CounterThread.ino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]
2018-08-26 master: reset the counter after logging
    [LoggerM24512.ino]
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2018-08-28 master: fix parameter for logging interval
    [counter.brd, counter.sch]
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2018-09-04 Modify entry height, move sensor further from edge
    [counterBox_v3_2.FCstd]
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2018-09-06 Make 5mm wider, adjust, add small extension, add hole below RJ11 connector, gates 7mm instead of 9mm and adjust
    [counterBox_v4.FCstd]
2018-09-06 Reposition pieces, make smaller extension on front/rear walls
    [counterBox_v4.FCstd]
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2018-09-09 counter: reset correctly the board
    [A_Parameters.ino]
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2018-09-09 counter: correct indentation of TotalUtilities
    [TotalUtilities.ino]
2018-09-11 Update of counter box, single hole for RJ11 connector and pins, elongates front and back wall
    [counterBox_v3_1.FCstd, counterBox_v3_1.dxf, counterBox_v3_2.FCstd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]
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2019-01-06 Change rotary encoder pinout to use interruptible pins on Atmega328p
    [lcd-screen.brd, lcd-screen.sch]
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2019-04-04 Adjust and add holes in ceiling + corresponding holes on L/R
    [counterBox_v4.FCstd, counterBox_v5.FCstd]
2019-04-04 Adjust existing holes and add 2 on ceiling, add corresponding holes to L/R walls
    [counterBox_v6.FCstd]
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

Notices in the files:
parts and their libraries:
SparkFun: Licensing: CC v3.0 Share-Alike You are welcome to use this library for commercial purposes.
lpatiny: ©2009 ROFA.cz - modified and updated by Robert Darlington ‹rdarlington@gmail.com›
